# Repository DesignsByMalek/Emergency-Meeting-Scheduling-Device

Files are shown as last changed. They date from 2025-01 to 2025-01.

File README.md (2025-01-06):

# Integrated Documentation: Remote Emergency Meeting Scheduling Device

This comprehensive documentation merges two interconnected projects, combining IoT-enabled emergency scheduling with a Flask application to manage Google services. Together, they offer a robust solution for automating critical communication tasks.

---

## Project Overview

### License

This project is licensed under the Apache License 2.0. You may obtain a copy of the License at:

[Apache License 2.0](http://www.apache.org/licenses/LICENSE-2.0)

Unless required by applicable law or agreed to in writing, software distributed under the License is distributed on an "AS IS" BASIS, WITHOUT WARRANTIES OR CONDITIONS OF ANY KIND, either express or implied. See the License for the specific language governing permissions and limitations under the License.

---

### Remote Emergency Meeting Scheduling Device
An open-source IoT solution designed to automate emergency meeting scheduling. It integrates seamlessly with Google Meet, SMS triggers, and email notifications to enhance reliability and efficiency.

### Flask Application
A lightweight web application utilizing Google services to automate calendar and spreadsheet management, with SMS processing to trigger calendar invites.

---

## Features

### IoT Device Highlights
- **SMS Trigger**: Activates the backend server via Twilio to initiate emergency meeting scheduling.
- **Battery Efficiency**: Operates for over a year on a single battery.
- **Design Optimization**: Iteratively developed for enhanced functionality and aesthetics.
- **Complete Resources**: Includes PCB designs, 3D models, schematics, and manufacturing files.

### Backend Capabilities
- **Google Workspace Integration**: Automates Google Meet scheduling and retrieves client data from Google Sheets.
- **Email Notifications**: Sends meeting details to participants promptly.
- **Scalability**: Handles multiple requests in real-time.

### Flask App Features
- **Google Calendar Management**: Creates and customizes Google Calendar events, including attendees, timings, and reminders.
- **Spreadsheet Management**: Reads, writes, and appends data dynamically to Google Sheets.
- **SMS Processing**: Logs SMS data, retrieves client details, and triggers calendar invites based on the content.

---

## Installation

### Prerequisites
- **Software**: Python 3.8+
- **Google APIs**: Enable Calendar and Sheets APIs in the Google Cloud Console.
- **API Accounts**: Twilio account for SMS handling; OAuth credentials for Google services.

### Setup Steps

#### Clone the Repository
```bash
git clone <repository_url>
cd <repository_folder>
```

#### Install Dependencies
```bash
pip install -r requirements.txt
```

#### Configure API Credentials
- Save the credentials JSON file from Google Cloud in the project directory.
- Add API keys and credentials in `config.py`:
  ```python
  CREDENTIAL_FILE = 'path_to_credentials.json'
  CALENDAR_TOKEN = 'path_to_google_calendar_token.json'
  SHEET_TOKEN = 'path_to_google_sheet_token.json'
  GOOGLE_SHEET = 'spreadsheet_id'
  ```

#### Start the Server
```bash
python app.py
```

---

## Usage

### IoT Device
1. Activate the device to send an SMS trigger to the backend.
2. The backend:
   - Retrieves client details from Google Sheets.
   - Schedules a Google Meet session.
   - Sends email notifications to participants.

### Flask App

#### Calendar Management
- Use the `set_calendar` function to create events:
  ```python
  from modules.calendar_v1 import set_calendar

  invitees = ["example1@gmail.com", "example2@gmail.com"]
  set_calendar(invitees)
  ```

#### Google Sheets Management
- Perform operations with the `GoogleSheets` class:
  ```python
  from modules.sheets_v1 import GoogleSheets

  gs = GoogleSheets()
  # Read data
  data = gs.read_data("Sheet1", "A1:C10")
  print(data)
  # Write data
  values = [["Name", "Age"], ["Alice", 25], ["Bob", 30]]
  gs.write_data("Sheet1", "A1", values)
  # Append data
  new_rows = [["Charlie", 35]]
  gs.append_data("Sheet1", new_rows)
  ```

#### SMS Processing
- Endpoint for SMS:
  ```bash
  /emergency-button/inbound-emergency
  ```
- Example payload:
  ```json
  {
    "From": "+1234567890",
    "To": "+0987654321",
    "Body": "button_id,event_type,battery_health"
  }
  ```
- Functionality:
  - Logs SMS details to the `SMS Logs` sheet.
  - Retrieves client emails from the `Client Info` sheet.
  - Triggers calendar invites based on the SMS content.

---

## GoogleAuthenticator Class for Google API Authentication

### Description
The `GoogleAuthenticator` class is designed to streamline authentication with Google API services. It handles token management, credential verification, and API service building, making it easier to integrate with Google services like Calendar and Sheets.

### How It Works

#### Authentication Process
- Ensures tokens are valid or refreshes them if expired.
- Launches a local server to authenticate and save credentials if no token exists.
- Saves credentials for future use.

#### Service Building
- Builds a Google API service using authenticated credentials for interaction with APIs like Calendar and Sheets.

#### Example Use
- Authenticate and initialize Calendar API service:
  ```python
  from services.authenticator import GoogleAuthenticator

  auth = GoogleAuthenticator(service_name='calendar', version='v3')
  credentials = auth.get_authenticated(token_path='path/to/token.json', scope=['https://www.googleapis.com/auth/calendar'])
  calendar_service = auth.auth_build('calendar', 'v3', credentials)
  print("Calendar API initialized.")
  ```

---

## Python Code Structure

```
project_root/
    |- app/
    |   |- modules/
    |   |   |- calendar_v1.py   # Manages Google Calendar events
    |   |   |- sheets_v1.py     # Manages Google Sheets interactions
    |   |- services/
    |       |- authenticator.py # Google API authentication utility
    |   |- routes/
    |       |- sms.py           # Handles SMS processing and calendar integration
    |   |- config.py                 # Configuration file for environment variables
    |- app.py # Entry point
```
## Python Flow Chart 
Backend Flow chart

---

## Future Improvements

- Enhance error handling for API operations.
- Add support for additional notification methods and triggers.
- Integrate further Google APIs for expanded functionality.
- PCB modifications for better user experience.

## IoT Device Code Highlights

### Key Functionalities
The Arduino code is designed to efficiently manage emergency meeting triggers. Below are the main highlights:

#### 1. **Low Power Mode**
The device leverages the `LowPower` library to maximize battery life by entering sleep mode when inactive.  
Example:
```cpp
#include "LowPower.h"

void sleepNow() {
    LowPower.powerDown(SLEEP_8S, ADC_OFF, BOD_OFF);  // Sleep for 8 seconds
}
```

#### 2. **Button Press Handling**
An interrupt is used to detect button presses and wake the device from sleep mode.
```cpp
const int buttonPin = 2;
volatile bool buttonPressed = false;

void setup() {
    attachInterrupt(digitalPinToInterrupt(buttonPin), wakeUp, FALLING);  // Attach interrupt
}

void wakeUp() {
    buttonPressed = true;  // Set flag on button press
}
```

#### 3. **SIM800L Communication**
The device uses `SoftwareSerial` to communicate with the SIM800L module for sending SMS triggers.
```cpp
#include <SoftwareSerial.h>

SoftwareSerial mySerial(3, 4);  // SIM800L Tx & Rx connected to pins 3 & 4

void sendSMS() {
    mySerial.begin(9600);
    mySerial.print("AT+CMGF=1
");  // Set SMS mode
    mySerial.print("AT+CMGS="+1234567890"
");  // Specify recipient
    mySerial.print("Emergency meeting triggered.
");  // Message content
    mySerial.write(26);  // End message with CTRL+Z
}
```
---

## Arduino Flow Chart
Arduino Flow chart

---

### Full Code
The complete code is available in the GitHub repository.

---

## Assembly Animation
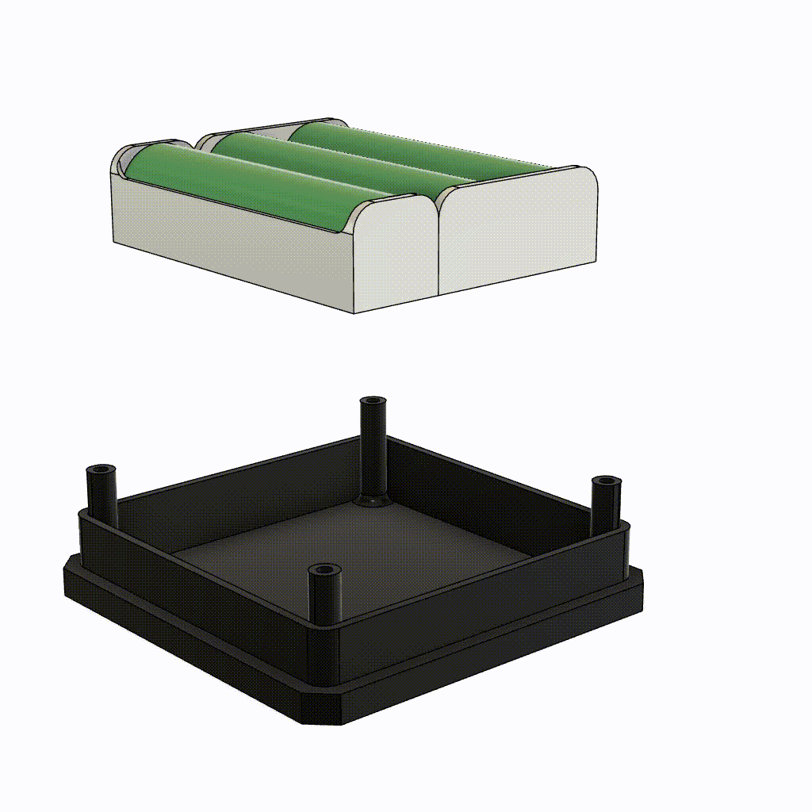
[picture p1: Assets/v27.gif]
Assembly Video


---

## Done By

This project was created and maintained by:

- [GitDevKarim](https://github.com/GitDevKarim)
- [DesignsByMalek](https://github.com/DesignsByMalek)

Feel free to reach out to us for any questions or contributions!

<div style="display: flex; justify-content: center; align-items: center;">
  <div style="text-align: center; margin-right: 20px;">
    <h3>GitDevKarim</h3>
    <span style="display: inline-block; margin-right: 10px;">
      <a href="https://github.com/GitDevKarim">
        
      </a>
    </span>
    <span style="display: inline-block;">
      <a href="https://linkedin.com/in/karim-jibai001">
        
      </a>
    </span>
  </div>

  <div style="text-align: center; margin-left: 20px;">
    <h3>DesignsByMalek</h3>
    <span style="display: inline-block; margin-right: 10px;">
      <a href="https://github.com/DesignsByMalek">
        
      </a>
    </span>
    <span style="display: inline-block;">
      <a href="http://www.linkedin.com/in/malek-itani-3a346b269">
        
      </a>
    </span>
  </div>
</div>

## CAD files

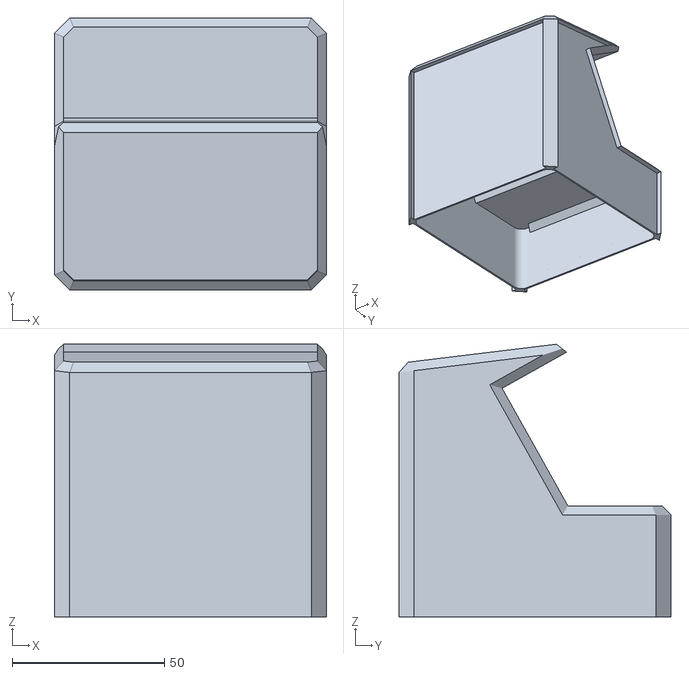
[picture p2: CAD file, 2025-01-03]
3D Models/For 3D Printing/main box w acryllic covers.stl
89.2 x 89.2 x 89.4

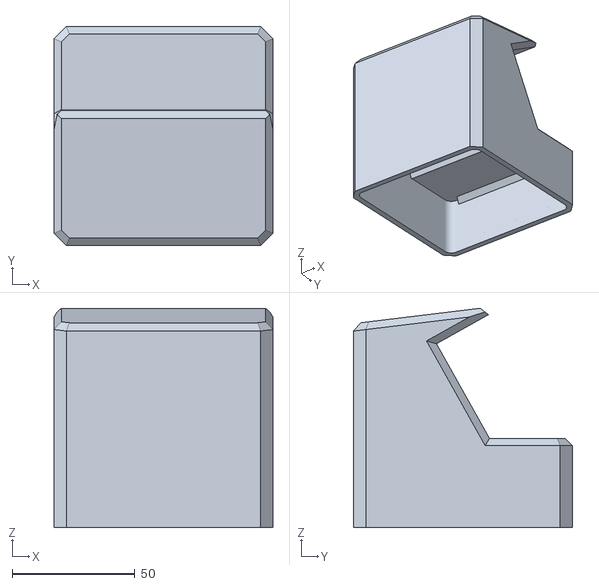
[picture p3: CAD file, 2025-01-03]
3D Models/For 3D Printing/main box full 3d print.stl
89.2 x 89.2 x 89.4

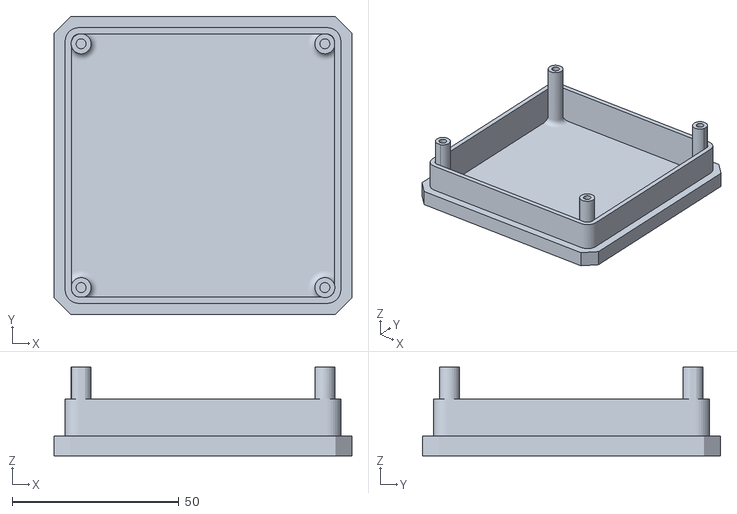
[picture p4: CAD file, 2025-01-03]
3D Models/For 3D Printing/Base.stl
89.2 x 89.2 x 26.6

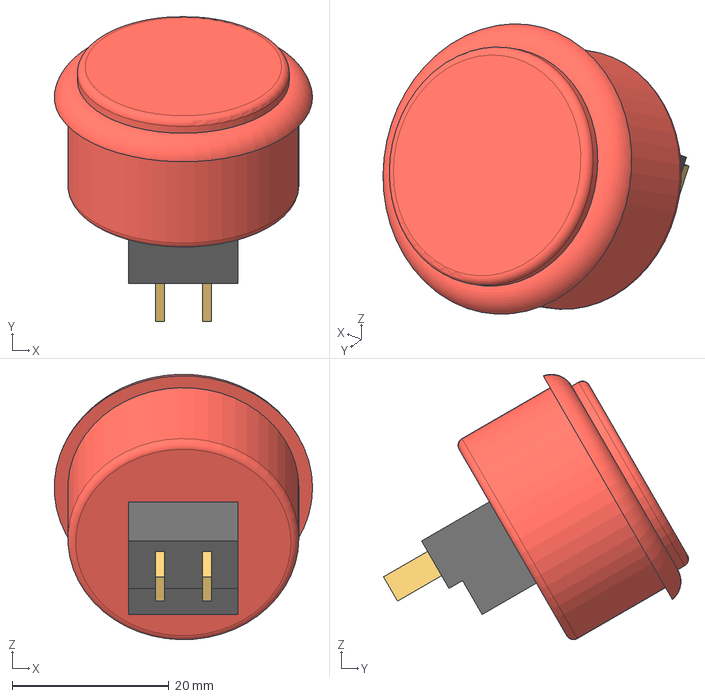
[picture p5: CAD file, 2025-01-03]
3D Models/sanwa button v5.step
33.0 x 38.9 x 33.9 mm

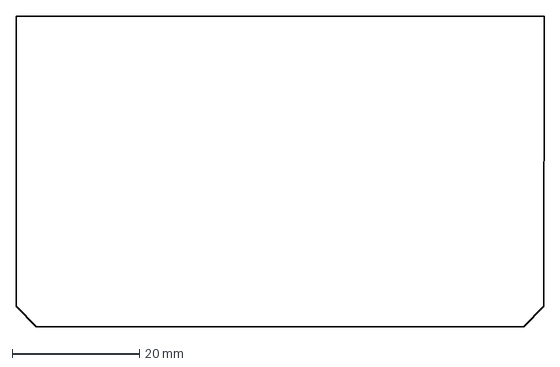
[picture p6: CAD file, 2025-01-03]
Laser Cutting Files/cover 3.dxf
83.0 x 48.8 mm

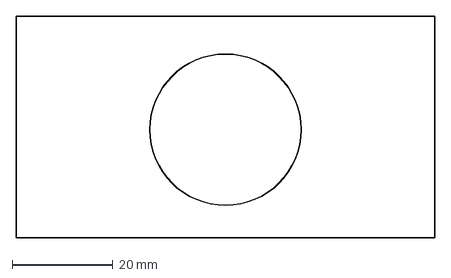
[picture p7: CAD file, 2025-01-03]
Laser Cutting Files/cover 1.dxf
82.9 x 43.9 mm

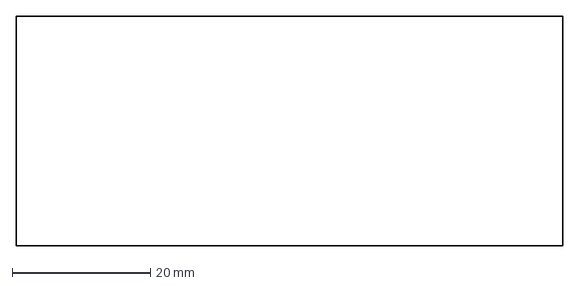
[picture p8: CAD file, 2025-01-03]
Laser Cutting Files/cover 7.dxf
79.0 x 33.2 mm

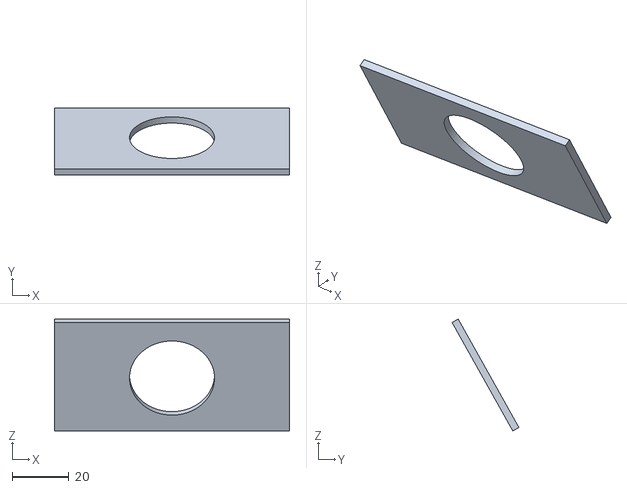
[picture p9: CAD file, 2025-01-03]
3D Models/For 3D Printing/button cover (if 3d printed).stl
82.9 x 23.6 x 39.5

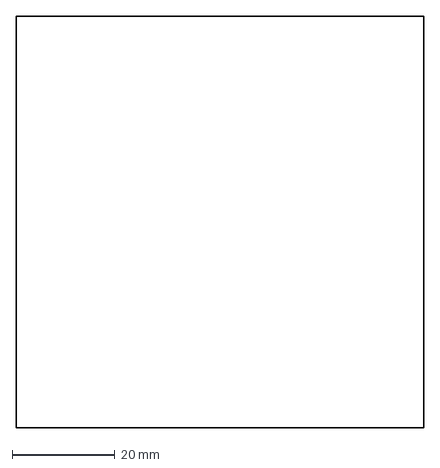
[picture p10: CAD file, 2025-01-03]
Laser Cutting Files/cover 5.dxf
79.0 x 80.0 mm

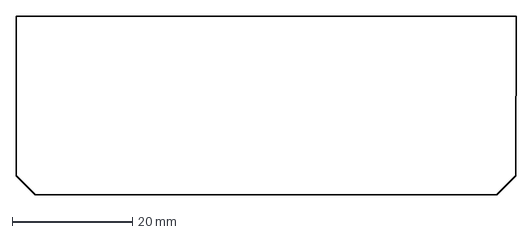
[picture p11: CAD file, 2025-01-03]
Laser Cutting Files/cover 2.dxf
83.0 x 29.6 mm

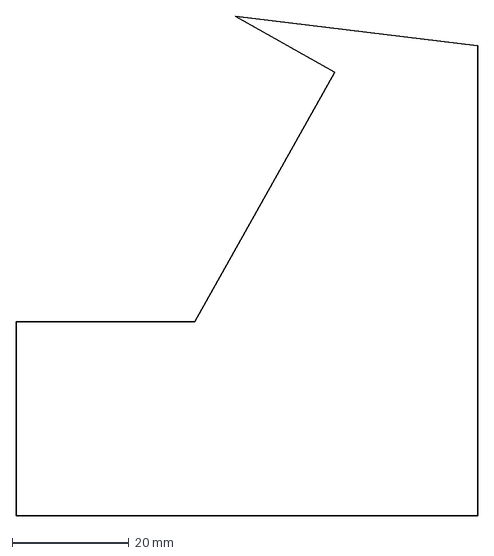
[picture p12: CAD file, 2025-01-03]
Laser Cutting Files/cover 6.dxf
79.0 x 85.6 mm

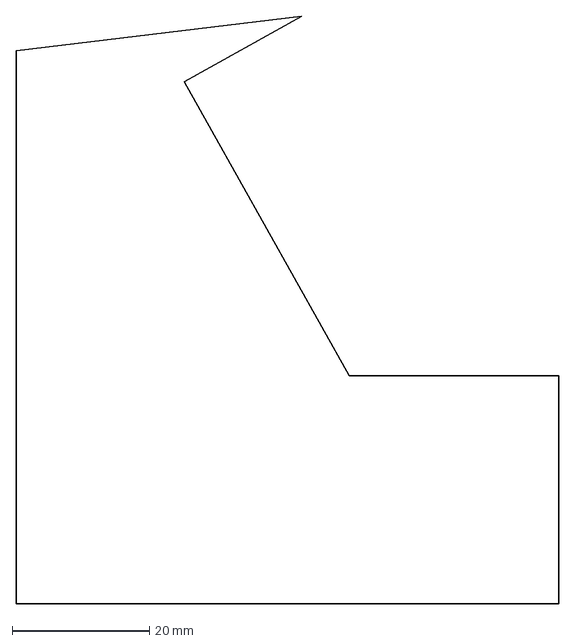
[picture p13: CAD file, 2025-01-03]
Laser Cutting Files/cover 4.dxf
79.0 x 85.6 mm

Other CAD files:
3D Models/sanwa button v5.f3d

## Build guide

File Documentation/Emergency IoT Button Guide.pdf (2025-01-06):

DesignsByMalek | GitDevKarim

i

## PRODUCT DESIGN AND MANUFACTURING

## OPEN-SOURCE DOCUMENTATION

## REMOTE EMERGENCY MEETING SCHEDULING DEVICE

## VERSION 1

Designed by

## ENG. MALEK M. ITANI

## ENG. KARIM A. JIBAI

Submitted to

## THE PUBLIC DOMAIN

## JANUARY 2025

ii

ABSTRACT

This report provides an in-depth exploration of the design, development, and

deployment of the Remote Emergency Meeting Scheduling Device, a versatile, open-source

IoT solution designed to streamline emergency communication. This device, a single-button

unit housed in an ergonomic enclosure, is built to trigger urgent Google Meet scheduling via

GSM-based SMS communication, circumventing potential vulnerabilities of Wi-Fi networks.

Its robust integration of hardware, software, and backend technologies ensures reliability,

security, and scalability, making it suitable for various industries such as corporate

environments, healthcare, education, and emergency services.

The report details the iterative design process, from 3D modeling the enclosure to

electronic circuit design and PCB layout, and backend server integration that manages

scheduling and notifications. It also includes comprehensive instructions for manufacturing,

assembly, and setup, allowing for replication and customization. By adhering to an open-

source model, this solution encourages adaptability, enabling users to customize the system

for diverse applications. Addressing challenges such as regulatory compliance, hardware

optimization, and software efficiency, the report positions the device as a practical, scalable,

and cost-effective emergency communication tool adaptable to many industries.

iii

## TABLE OF CONTENTS

1.1- | Background information
1.2- | Aim of the Project
2.1- | Electronic Circuit Design
2.2- | Arduino Programming
2.3- | Backend Code and Server Setup Instructions
2.4- | 3D Modeling
2.5- | Manufacturing and Assembly Instructions
3.1- | Results
3.2- | Trouble Shooting
3.3- | Future Improvements
3.4- | Regulations and Legality

## 1. INTRODUCTION

### 1.1 Background Information

In fast-paced and high-stakes environments, the ability to rapidly respond to

emergencies is essential. Whether in corporate settings, healthcare facilities, educational

institutions, or industrial environments, effective communication during crises can mitigate

risks, minimize downtime, and save lives. Recognizing this critical need, the Remote

Emergency Meeting Scheduling Device was developed as an innovative, open-source IoT

solution designed to simplify and accelerate emergency response coordination.

The device operates with a single press of a button, sending a GSM-based SMS to a

backend server that schedules a Google Meet session and sends instant notifications to

relevant stakeholders. Unlike traditional methods that depend on manual scheduling or Wi-Fi

connectivity, this solution offers unmatched reliability by leveraging GSM communication,

making it suitable even in areas with limited internet access. Additionally, the system's

scalability and adaptability allow it to be applied across various sectors. For example, in the

corporate world, it ensures urgent client communication; in healthcare, it can summon

emergency teams; in educational institutions, it facilitates swift administrative coordination

during crises.

The project’s design emphasizes security, user-friendliness, and aesthetics. Its long-

lasting battery supports over a year of uninterrupted operation, while its modular backend

system integrates seamlessly with popular tools like Google Sheets, Twilio, and Google

Calendar. Designed to be replicated, modified, and scaled, this open-source solution provides

a reliable and affordable emergency communication tool adaptable to various industries,

empowering organizations to manage crises effectively and efficiently.

### 1.2 Project Aim

The aim of this project is to create an open-source, scalable IoT device that offers a

reliable, user-friendly, and secure solution for emergency meeting scheduling. The device is

designed to be adaptable across various fields, such as corporate environments, healthcare,

educational institutions, and emergency response scenarios. Its primary objectives include

simplifying emergency communication by enabling users to schedule urgent Google Meet

meetings with a single button press, ensuring that notifications and meeting links are quickly

delivered to all stakeholders. The system is built with scalability and flexibility in mind,

allowing it to meet the diverse needs of industries ranging from medical teams to corporate

crisis management. The device is optimized for long-lasting operation, with over a year of

battery life achieved through hardware and software enhancements, ensuring reliable

performance with minimal maintenance. To enhance security, the device utilizes GSM

technology, bypassing Wi-Fi network vulnerabilities to provide a stable and secure

communication channel. Additionally, the project will be open-source, with detailed

documentation, code, and design files available for users to replicate, customize, and scale

the device to suit their specific requirements. The device will also feature an aesthetic and

functional design, balancing professional appearance with intuitive usability. By combining

robust hardware, efficient software, and a user-centric approach, this device aims to

transform emergency communication, providing a cost-effective and versatile solution for a

wide range of applications. The open-source nature invites collaboration and innovation,

empowering the community to expand the device’s potential beyond its original design.

Figure 1 shows the block diagram of the project functionality.

FIGURE 1: FLOW DIAGRAM OF HOW THE DEVICE SHOULD WORK

## 2. METHODS

### 2.1 Electronic Circuit Design

### 2.1.1 Components

This section outlines the steps taken to design the circuitry for the IoT emergency

button device, detailing the components used, their roles, and the process to create a reliable

and functional electronic system. The button serves as an auxiliary device, primarily

responsible for sending SMS messages via GSM to initiate the meeting scheduling process.

Key requirements include a battery life exceeding 365 days, reliable signal connectivity even

in challenging conditions such as underground environments, and the use of rechargeable

lithium-ion batteries for long-term, low-maintenance operation. The design ensures robust

GSM network connectivity under tough conditions, making the device dependable in critical

scenarios. Table 1 Shows the electronic components used in this project:

### 1. Arduino Nano

The Arduino Nano is a compact, microcontroller-based

development board based on the ATmega328P

microcontroller. It is designed to be breadboard-friendly,

making it ideal for prototyping, embedded systems, and

small electronics projects. The board operates on a 5V

supply, powered through a mini-USB connection or an

external power source. It features 14 digital input/output

pins, 8 analog inputs, a 16 MHz clock speed, and a built-in

USB-to-serial converter, making it suitable for and IoT

(Internet of Things) system.

FIGURE 2: ARDUINO NANO

### 2. SIM800L V2 EVB with Antenna

The SIM800L V2 is an upgraded, more reliable GSM/GPRS

module for SMS, voice calls, and data transfer over 2G

networks. It consumes 2-10mA in idle mode and 100-200mA

when sending SMS. During data transfer or calls, it can draw

up to 2A, requiring a stable 5V power supply. The V2

version includes a more powerful antenna for better signal

FIGURE 3: SIM800L V2 EVB reception, making it ideal for IoT, remote monitoring, and

cellular communication projects.

### 3. MT3608 DC-DC Step Up Converter

The MT3608 is a compact and efficient DC-DC step-up

(boost) converter that increases input voltages from 2V to

24V up to an adjustable output of 5V to 28V. It can deliver

up to 2A of output current, depending on input and output

conditions. Known for its high efficiency, typically around

85-90%, the MT3608 is commonly used in battery-powered

devices, portable power supplies, and LED drivers. Its small

size and reliability make it ideal for various electronics

projects requiring voltage step-up functionality.

FIGURE 4: MT3608

### 4. HK4100F 3V Relay

The HK4100 is a compact 3V relay commonly used in low-

power electronic projects for switching high-current loads

with a low-voltage control signal. It features a 3V coil

voltage and can handle up to 10A of current at 120V AC or

30V DC. This relay is widely used in automation systems,

control circuits, and devices requiring safe switching of high-

power components. Its small size and reliable performance

make it a popular choice for microcontroller-based

applications where low voltage control and high current

switching are needed.

FIGURE 5: HK4100F 3V

RELAY

### 5. SMA Female IPX Coaxial Cable (Right Angled)

The SMA Female to IPX Coaxial Cable is designed for

connecting devices with SMA female connectors to those

with IPX connectors, providing reliable RF signal

transmission. It is commonly used in wireless

communication systems, antennas, and RF modules. This

cable is available in a version with a PCB-mounted SMA

female connector featuring four legs for secure mounting. It

offers flexible, low-loss signal transmission, making it ideal

for compact electronics projects, IoT applications, and

devices requiring high-frequency signal connectivity.

FIGURE 6: ANTENNA SMA

TO IPX CONNECTOR

6. 1N4007 Diode

The 1N4007 is a general-purpose rectifier diode commonly

used for rectifying AC to DC in power supply applications. It

has a peak reverse voltage of 1000V and can handle a

forward current of up to 1A. In addition to its use in power

supplies, the 1N4007 is often used as a freewheeling diode

(flyback diode) across relay coils to protect circuits from

voltage spikes generated when the relay is turned off. Its

durability, high voltage rating, and reliability make it ideal

for protecting sensitive components in automotive, industrial,

and electronic systems.

FIGURE 7: 1N4007 DIODE

### 7. JST XH 2.54 Male and Female Connectors

The 2-pin JST female and male connectors are commonly

used in electronics for providing a secure and compact

connection between two components. These connectors are

widely used in power supplies, batteries, and signal

transmission applications. The male connector typically has

two pins that are inserted into the female connector, ensuring

a reliable connection. They are designed for easy and secure

installation, making them ideal for use in various projects,

including robotics, IoT devices, and other compact electronic

systems that require efficient, low-profile connections. For

this application 3 of 3 each are required.

FIGURE 8: JST

CONNECTORS

8. 104 Ceramic Capacitor

The 104 ceramic capacitor is a widely used passive

component with a capacitance of 100nF (nano-farads), often

utilized for decoupling, filtering, and smoothing in electronic

circuits. It helps prevent accidental button presses caused by

electrical noise by stabilizing the voltage and reducing signal

interference. The capacitor is known for its small size,

reliability, and stability across a range of voltages, making it

ideal for power supply circuits, signal filtering, and noise

reduction. It is commonly used in consumer electronics,

automotive, and industrial devices.

FIGURE 9: 100NF CERAMIC

CAPACITOR

### 9. Sanwa 30mm Red Button

The 30mm Sanwa red button is a durable and widely used

push-button switch commonly found in arcade machines,

gaming controllers, and electronic projects. Known for its

high-quality construction, it provides reliable operation and a

tactile feel when pressed. This button is often used for user

input in various applications, and its large size makes it easy

to press. It is designed to minimize accidental activation,

ensuring precise control, and is ideal for projects requiring

robust, responsive switches, such as in gaming, robotics, and

DIY electronics. This model comes with a screw mechanism

to fix it securely in place.

FIGURE 10: SANWA RED

BUTTON

10. 18650 Battery

The 18650 battery is a widely used rechargeable lithium-ion

cell known for its high energy density and long cycle life.

With a nominal voltage of 3.7V and typical capacities

ranging from 1800mAh to 3500mAh, it is commonly used in

portable electronics, power tools, and electric vehicles. The

18650 battery is known for its reliability, compact size, and

efficiency, making it ideal for applications requiring a stable

power source, such as in battery packs for laptops,

flashlights, and IoT projects. Three will be used for this

project.

FIGURE 11: 18650 LITHIUM

ION BATTERY

### 11. Single Cell 18650 Battery Holder

The single-cell 18650 battery holder is designed to securely

hold a single 18650 lithium-ion battery, providing a reliable

power source for various electronic projects. With its

compact and durable design, it is ideal for powering low-

voltage devices, such as an Arduino board. This holder

ensures easy installation and removal of the battery, while

maintaining a stable connection to power the Arduino and

other small electronics. It is commonly used in DIY projects,

robotics, and portable power supplies, offering an efficient

solution for battery-powered

FIGURE 12: 18650 SINGLE

CELL HOLDER

### 12. Two Cell Parallel 18650 Battery Holder

The 2-cell parallel 18650 battery holder is designed to hold

two 18650 lithium-ion batteries in parallel, providing

increased capacity and current output. This holder ensures a

stable and reliable power source for high-current devices,

such as the SIM800L module, which requires more current

than a single cell can provide. By connecting the batteries in

parallel, the holder doubles the available capacity while

maintaining a consistent voltage of 3.7V, making it ideal for

powering power-hungry components like the SIM800L,

which is used in IoT and communication projects.

FIGURE 13: 18650 TWO

CELL PARLLEL HOLDER

### 13. Male Pin Headers

Male pin headers are widely used for PCB mounting,

providing a secure connection for electronic components.

These headers consist of rows of metal pins, usually spaced

2.54mm apart, which are soldered onto the PCB. They are

commonly used to connect components, such as sensors or

modules, to the PCB, allowing for easy and removable

connections. They are a standard choice for creating

customizable and accessible connections in electronic

designs.

FIGURE 14: MALE PIN
HEADERS

### 2.1.2 Circuit Functionality and Explanation

Many Iterations of the circuit were made but for this section we will only discuss the

working circuit. The circuit design revolves around the Arduino as the central control unit,

with careful attention to power management, signal integrity, and efficient use of

components. The Arduino is powered by a single 18650 lithium-ion battery, this dedicated

power source provides consistent performance and isolates the Arduino's operation from

other high-current sections of the circuit.

The button is wired to one of the Arduino's GPIO pins, specifically interrupt pin 2, as

the Nano has limited interrupt pins (2 and 3). A debounce capacitor is placed across the

button's terminals to smooth out mechanical noise and eliminate erratic signals caused by

button bounces and random noise, ensuring a clean and reliable signal is sent to the Arduino.

The button serves as the primary input mechanism, triggering the circuit's operations. When pressed, it connects the pin to ground, providing a suitable trigger for the Arduino to wake

up.

A 3V relay is incorporated to manage the power supply to the SIM module. The relay

coil is driven directly by the Arduino's GPIO output through a low-current connection. A

flyback diode is placed across the relay coil to handle voltage spikes generated when the coil

is de-energized. This protects the circuit from damage and ensures the longevity of the relay.

The relay serves as an electrical switch, allowing the SIM module to remain completely

disconnected from its power source until required, thereby conserving energy.

The SIM800L V2 was used for this project as the SIM800L V1, after rigorous testing,

was found to be less reliable than the V2 and required 2 additional resistors to operate. The

SIM800L V1 should work fine for this circuit but we decided to go with the V2 as it required

less trouble shooting and simple at the expense of it being operated at 5V instead of 3.7-4.2.

Also, the antenna that came with the SIM800L V1 had very poor connectivity and required a

separate antenna to be bought with it whereas the V2 came with a robust antenna. The SIM

module is powered by two parallel 18650 lithium-ion batteries, chosen for their ability to

provide the substantial current required during GSM transmission. These batteries are

connected through appropriate wiring to ensure a stable power supply, with an MT6803 boost

converter employed to step up the lithium-ion batteries' voltage range of 3.5–4.2V to a stable

5V. This boosted voltage is necessary to meet the operating requirements of the SIM module

and maintain its performance under varying power conditions. Additionally, bypass

capacitors are strategically placed close to the SIM module's power input. These capacitors

play a crucial role in mitigating voltage fluctuations that may arise from sudden current

surges during transmission, effectively smoothing out the power supply and ensuring the SIM

module functions reliably even under demanding conditions. More information on the

sim800L can be found in reference [1].

Following the manufacturer's recommendations, it is best practice to turn on the SIM

module by first connecting it to ground and then supplying Vcc. In low-voltage systems, such

as those operating at 3.7V, both high-side and low-side switching can be challenging. Low-

side switching, in particular, may suffer from voltage drops across the MOSFET, leading to

inefficiencies and insufficient voltage for reliable operation. In these cases, a relay offers a

simpler and more effective solution for controlling the SIM module’s power supply,

bypassing the complexities of MOSFET switching and ensuring stable power delivery. Make sure to wire a freewheeling diode across the terminals of the relay coil to prevent a reverse

current in the direction of the Arduino when the relay turns off and thus damaging it.

An external antenna is attached to the SIM module via a dedicated connector to

enhance signal reception. This antenna is positioned to maximize GSM network connectivity,

ensuring stable communication even in challenging environments such as underground

locations. The overall layout of the circuit prioritizes efficiency and reliability, making the

design robust and suitable for long-term use. Figure 13 shows the block diagram of the

circuit.

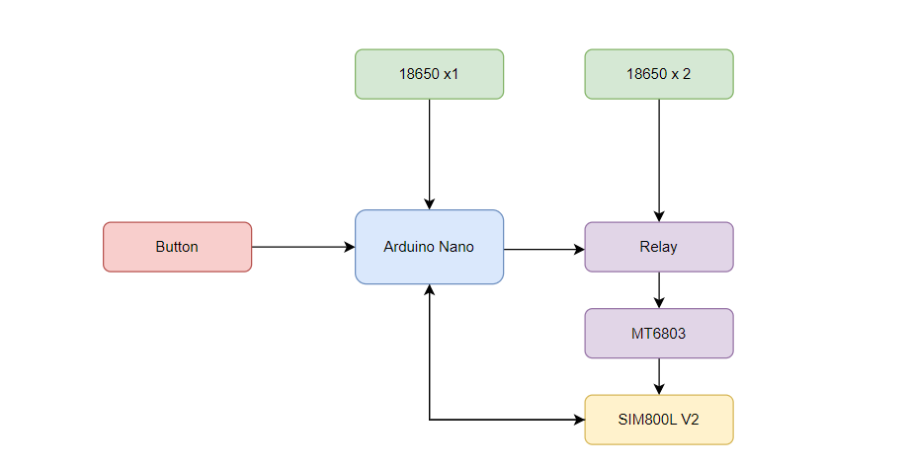
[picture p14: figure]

FIGURE 15: BLOCK DIAGRAM OF CIRCUIT

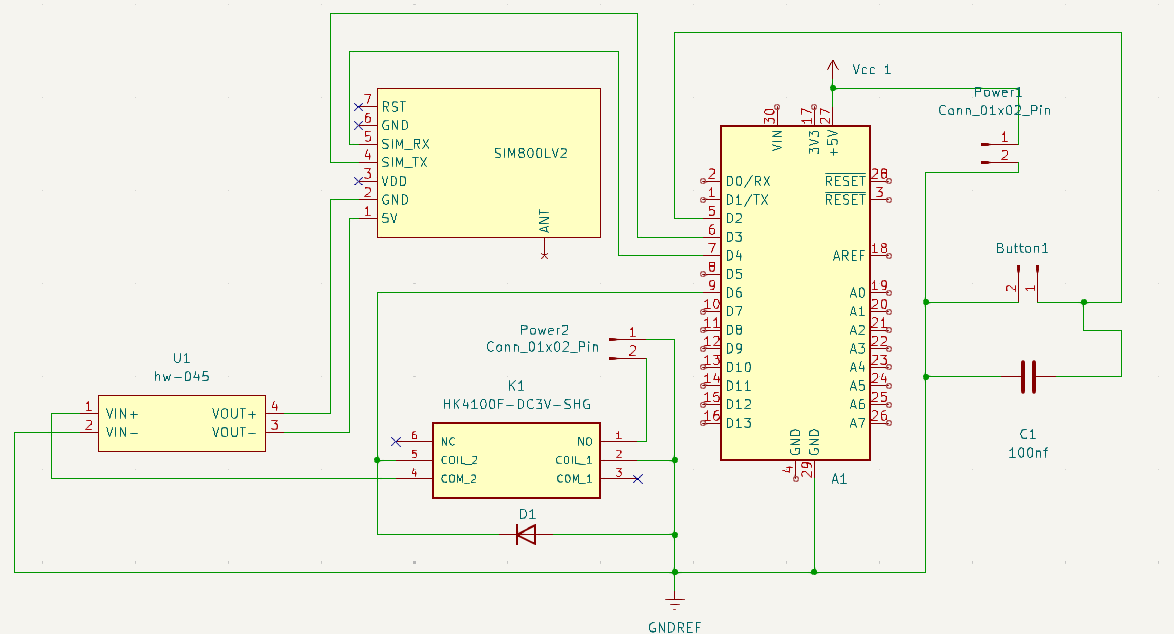
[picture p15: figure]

FIGURE 16: KICAD SCHEMATIC OF CIRCUIT.

The circuit was designed using KiCad, the schematic is shown in figure 15. This

schematic can be replicated on a prototyping board for a better understanding of how the

system works. When using Ki-Cad, make sure to install the necessary libraries and Files to

modify the circuit. Some files are custom made. Feel free to explore KiCad libraries.

There are several important considerations regarding the circuit that should be kept in

mind to ensure optimal performance and avoid potential mistakes. These notes will help

increase the efficiency of the system and ensure smooth operation throughout the project.

The relay is used in this project to control the power supply to the SIM module. Below

is the pinout diagram of the relay:

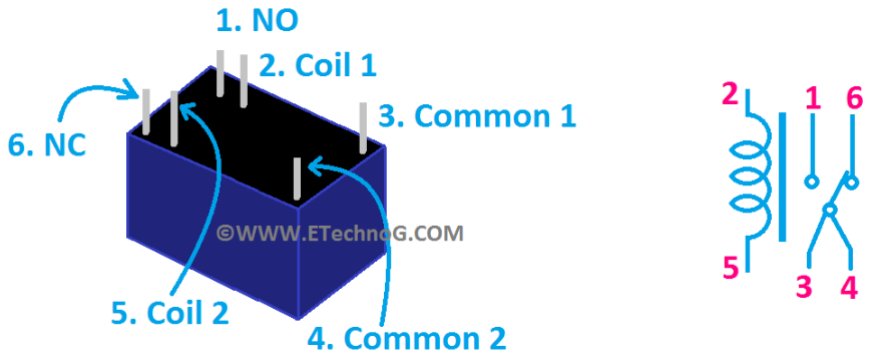
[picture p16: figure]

FIGURE 17: RELAY PINOUT

The relay uses the following pins for operation: Pin 2 (Control, IN) is connected to the

control signal from the Arduino. Pin (Normally Open, NO) connects to the load (SIM

module), while Pin 4 (Common, COM) is the shared pin used to switch the load on or off. Pin

6 (Normally Closed, NC) provides an alternative connection when the relay is in the off state

(Not Connected). A freewheel diode, also known as a flyback diode, is crucial for protecting

the circuit from voltage spikes caused by inductive loads, such as relays or motors. When the

relay coil is de-energized, the collapsing magnetic field can generate a high voltage in the

opposite direction, potentially damaging components. The freewheel diode provides a safe

path for the current to dissipate, preventing damage to the circuit and ensuring reliable

operation.

The Arduino Nano’s TX (Transmit) and RX (Receive) pins are connected to the

SIM800L module for serial communication. Specifically, Pin 3 on the Arduino Nano (RX) is

used for TX of the SIM module, and Pin 4 is used for RX of the SIM. This setup allows the

Arduino to send and receive data from the SIM800L, such as commands for sending SMS or

making calls. If there is no communication between the SIM module and the Arduino, make

sure these pins are connected properly.

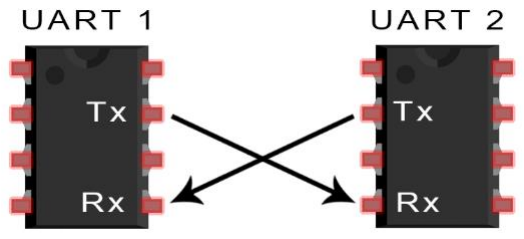
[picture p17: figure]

FIGURE 18: SERIAL COMMUNICATION BETWEEN ARDUINO AND SIM MODULE

For the power and button connections, 2-pin JST 2.54mm female connectors are used.

These connectors provide a secure and easy-to-use interface for plugging in the power supply

and the button that controls the SIM module.

There are three male JST connectors: Power 1, Power 2, and Button. These connectors

are color-coded for easy identification, with the red wire indicating positive voltage (Vcc)

and the black wire indicating ground (GND). It is important to ensure that all three male JST

connectors are consistent, with the red and black wires on the same side of each connector.

Warning: Make sure the red and black wires are on the same side of all three

connectors to avoid reversing the connections. Incorrect connections may cause damage to

the circuit or components.

Power 1 is connected to a single lithium-ion battery, as it is solely responsible for

powering the Arduino, which has a relatively low current requirement. Power 2, on the other

hand, is dedicated to powering the SIM module. To meet the SIM module's high current

demand, especially during its boot-up phase, two lithium-ion batteries are connected in

parallel. This setup prevents voltage drops in the Arduino's power supply, which could

otherwise cause it to reset when the SIM module draws its high inrush current during startup.

Common ground is established between the 2 power supplies so that the circuit functions

properly. The sim module cannot communicate with the Arduino if there is no common

ground.

### 2.1.3 PCB Design

To integrate all components into a single compact unit, a PCB (Printed Circuit Board)

was designed using KiCad. This design ensures a neat arrangement of components with

minimal wiring, reducing noise and improving reliability. To keep things compact, the pcb

size is set to be 8 x 8 cm with screw holes on the corners to accommodate 3mm screws. The

traces are designed to avoid passing under the antenna to eliminate noise, and to keep the

MT3608 as far as possible from the GSM module as possible to reduce signal interference

and noise. For simplicity and cost efficiency, the circuit was implemented as a single-layer

PCB, which is easier to manufacture and more affordable. The prototype PCB was

manufactured in-house but can also be easily outsourced to companies like JLCPCB or

PCBWay, with much higher quality and fast delivery, often within a week, for just a few

dollars. Figure 19 shows the PCB Layout.

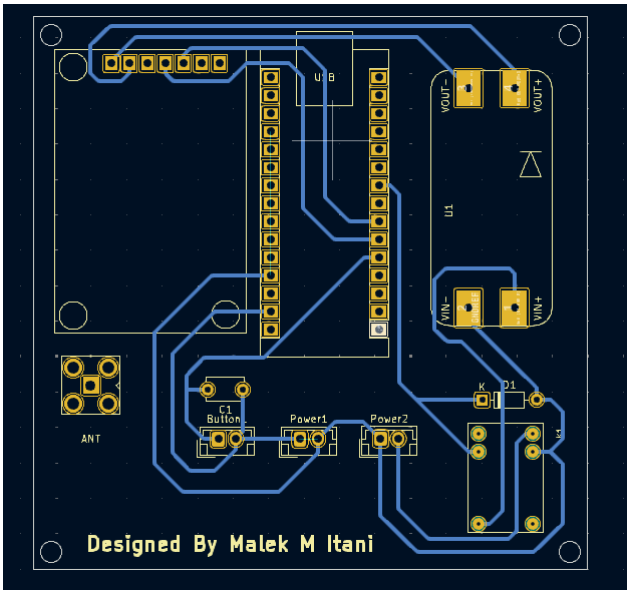
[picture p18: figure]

FIGURE 19: PCB LAYOUT OF THE CIRCUIT

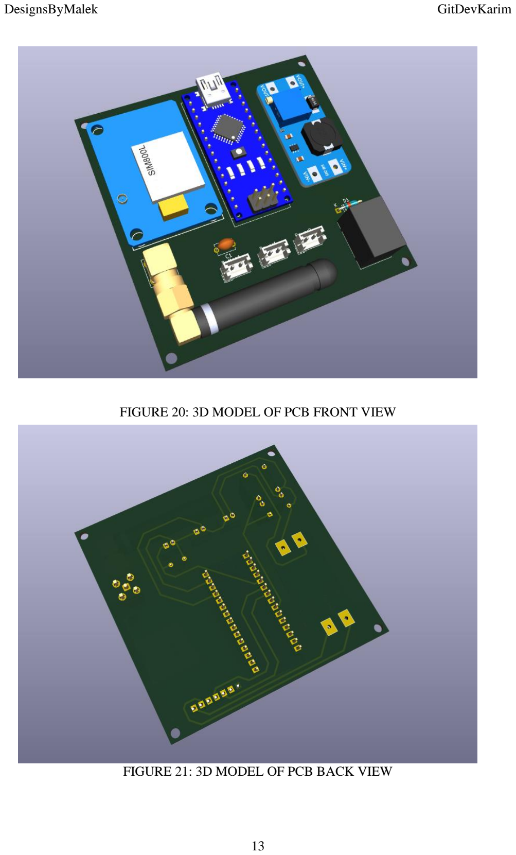
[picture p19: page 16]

FIGURE 20: 3D MODEL OF PCB FRONT VIEW

FIGURE 21: 3D MODEL OF PCB BACK VIEW

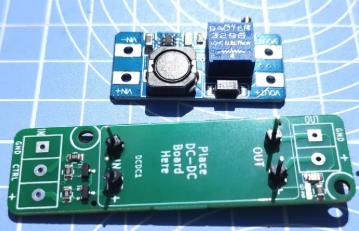
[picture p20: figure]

FIGURE 22: SAMPLE MOUNTING OF MT3608 ON PCB

For the MT3608, male pin headers should be soldered on the pad holes first then the

module should be soldered and mounted as shown in the example board in figure 23:

The antenna mounts on the PCB and is soldered firmly in place using the SMA through

hole component which is spaced and designed to keep it compact and inside the PCB

boarders. This concludes the electronic design part of the project.

### 2.2 Arduino Programming

The Arduino code serves as the foundation for a low-power IoT device that sends an

SMS notification when a button is pressed. It is designed to operate efficiently by utilizing

interrupt-driven inputs and low-power sleep modes. When a button press is detected, the

system wakes up from sleep, powers on the SIM800L GSM module, connects to the cellular

network, sends a pre-programmed SMS, and then powers down again to conserve energy.

This setup is ideal for applications such as emergency alerts or remote monitoring systems.

The code integrates the SoftwareSerial library for communication with the SIM800L module

and the LowPower library to implement energy-saving features. The entire code is included

in Appendix A for reference. The block diagram of the code is shown in figure 24.

FIGURE 23: ARDUINO CODE FLOW DIAGRAM

The code begins with the inclusion of two libraries. The SoftwareSerial.h library allows

serial communication with the SIM800L module using non-default pins, freeing up the

Arduino’s hardware UART for debugging. The LowPower.h library provides functionality to

place the Arduino into deep sleep, minimizing power consumption when the device is idle.

Pin definitions are established next, with buttonPin (pin 2) assigned to the button input,

relayPin (pin 6) controlling the MOSFET that powers the SIM800L, and ledPin (pin 13) for

status indication via an LED. A boolean variable, buttonPressed, is used as a flag to indicate

when the button is pressed. Note that for V1 of this product, the Arduino’s onboard LED is

used.

The SoftwareSerial object, mySerial, is instantiated to communicate with the SIM800L

module via pins 3 (Rx) and 4 (Tx). This enables the Arduino to send and receive AT

commands to the GSM module.

The wakeUp() function is defined as an interrupt service routine (ISR) that sets the

buttonPressed flag to true whenever the button is pressed. This ISR is triggered by a falling

edge on buttonPin. A falling edge is used as a trigger because the button is wired with a

pullup resistor meaning that initially, its set high, and it becomes low when the button is

pressed and the interrupt pin is conneted to ground

In the setup() function, all pins are configured, and initial states are established. The

buttonPin is set as an input with an internal pull-up resistor to ensure stability, while relayPin

and ledPin are set as outputs, starting in the LOW state to ensure the SIM800L module is

initially powered off. Serial communication with the SIM800L is initialized at 9600 baud.

The main program logic resides in the loop() function. It begins by attaching an

interrupt to the buttonPin to detect a button press, then places the Arduino into a deep sleep

mode using LowPower.powerDown(). The device remains in this state until the ISR (Interupt

service routine) is triggered by the button press. Upon waking, the interrupt is detached, and

the LED briefly flashes to indicate activity.

When using an interrupt to wake up the Arduino from sleep mode, pressing the button

again after the Arduino has already woken up won't trigger another interrupt because the

interrupt flag has already been cleared when the Arduino is woken up. In most

microcontrollers, including the Arduino, interrupts are edge-triggered, meaning they only

respond to changes in the signal (e.g., a button press or release). When the Arduino wakes up,

the interrupt flag is cleared, and the microcontroller no longer detects a new edge unless the

button is pressed and released again, causing another transition in the signal. Simply pressing

the button again while the Arduino is awake won't generate a new interrupt signal, as there is

no edge (change in state) being detected at that moment.

The code then powers on the SIM800L module by setting relayPin to HIGH and waits

for two seconds to allow the module to stabilize. The waitForNetwork() function is called to

check the network connection status by sending the AT+CREG? command to the SIM800L

repeatedly for up to 60 seconds. If the network connection is successful, the sendSMS()

function is invoked to send an SMS. The SMS is sent using a series of AT commands: the

mode is set to SMS text format (AT+CMGF=1), the recipient's phone number is specified,

and the message content is sent, followed by a special character (Ctrl+Z) to complete the

transmission.

After the SMS is sent, the SIM800L module is powered off by setting relayPin to

LOW. The LED flashes again to indicate that the system is returning to sleep mode. The loop

then restarts, reattaching the interrupt and placing the Arduino into deep sleep until the next

button press.

The code includes additional utility functions such as updateSerial() to facilitate

debugging by forwarding GSM module responses to the serial monitor. Overall, the program

is designed to be efficient and modular, ensuring low power consumption while reliably

handling GSM communication. The full Arduino code is provided in Appendix A for

implementation and further study.

For debugging purposes, you can uncomment the Serial.print statements by removing

the 2 slashes in the code to view real-time data and monitor the Arduino’s behavior via the

Serial Monitor. Currently, these Serial.print statements are commented out to reduce

unnecessary serial communication during normal operation. By uncommenting them, you can

track variable values, execution flow, and other important outputs, which can be very helpful

in identifying issues or verifying that the circuit and code are functioning as expected.

### 2.3 Backend Code

The backend system for the IoT emergency button is a robust and modular platform

designed to manage emergency communication seamlessly. It serves as the bridge between

the IoT device, Google services, and end-users by processing button triggers, scheduling

Google Meet sessions, and sending email notifications. The system is implemented using

Flask, a lightweight Python web framework, and integrates essential APIs, including Twilio

for SMS handling, Google Calendar for meeting scheduling, and Google Sheets for client

data management. This modular approach ensures scalability, maintainability, and fault

tolerance, making it ideal for handling real-time events efficiently. Figure X shows the flow

diagram of the backend.

The database in this system is designed to manage client information and their

interactions effectively. It includes two main tables: Client Data and SMS Logs. The Client

Data table stores essential details about each client, such as their name, email(s), phone

number, and a unique button ID, The client data is submitted via a Google Form. Multiple

emails for a single client can be added, separated by commas, allowing the system to handle

clients with more than one contact. The SMS Logs table records the events triggered by button presses, such as event types (button press or battery health), along with the

corresponding button ID and battery health information. These Tables can be found and

monitored on Google sheets. The two tables are connected through the button ID, linking the

client details from the Client Data table with the events in the SMS Logs table. This structure

allows the system to identify relevant clients and their associated emails when scheduling

meetings, ensuring that all the specified email addresses for a client are notified of the events

recorded in the logs.

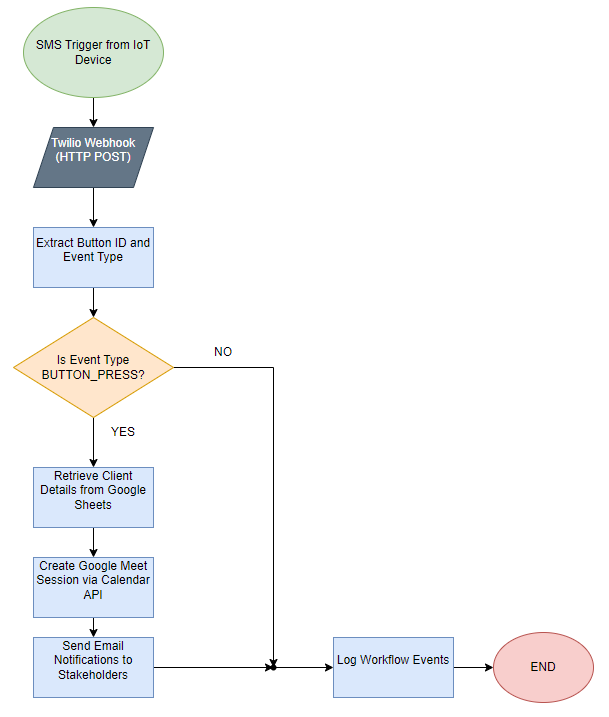
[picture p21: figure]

FIGURE 24: BACKEND CODE FLOW DIAGRAM

The backend workflow begins with the IoT device sending an SMS trigger to a Twilio-

managed phone number. Twilio's webhook forwards this SMS as an HTTP POST request to

the backend’s designated endpoint, where the system extracts the relevant details such as

button ID, event type, and battery health status. Depending on the event type, the backend takes different actions. For a button press event, it retrieves client data from Google Sheets

using the button ID, schedules a Google Meet session via the Google Calendar API, and

sends email notifications containing meeting details to clients and team members. For a

battery health event, the system logs the information without scheduling a meeting, providing

a comprehensive log for monitoring purposes.

The backend’s modular structure ensures streamlined operations. The calendar_v1.py

module manages Google Calendar interactions, authenticating with Google APIs to create

events that include Google Meet links, predefined durations, attendee lists, and reminders.

The sheets_v1.py module facilitates seamless integration with Google Sheets, allowing

dynamic data retrieval and updates. It supports reading client information, appending SMS

logs, and managing large datasets efficiently. The sms.py route processes incoming SMS

data from Twilio, determines the event type, and triggers appropriate actions, such as meeting

scheduling or logging battery health. The authenticator.py service simplifies API

authentication, ensuring secure and uninterrupted access to Google services.

Scalability and reliability are key features of the backend. It incorporates

comprehensive error handling to manage API failures, network issues, and unexpected data

formats. Monitoring tools provide insights into system performance, ensuring timely

detection and resolution of anomalies. Redundancy in critical components minimizes

downtime, making the system robust and efficient for real-world applications.

Setting up the backend requires enabling Google Sheets and Calendar APIs in the

Google Cloud Console and securely storing API credentials in a JSON file. The application is

configured through a .env file containing essential environment variables, such as API keys

and Google Sheet IDs. The repository is easily installed by cloning the project and running

the app.py file to launch the Flask server. This setup ensures a streamlined deployment

process, enabling rapid implementation of the IoT emergency button system.

By automating repetitive tasks, such as meeting scheduling and email notifications, the

backend significantly enhances the responsiveness and reliability of the emergency button

system. Its integration with powerful tools and APIs ensures that the system remains

adaptable and scalable, ready to handle growing demands and evolving use cases. This

backend is a testament to the efficiency of modular design in creating a high-performance,

user-centric solution.

Here’s a step-by-step explanation of the code:

### 2.3.1. Modules:

init Module

- Purpose: Acts as an initializer, importing and exposing key modules.
- Key Elements:
- set_calendar from calendar_v1 is renamed to calender_invite.
- GoogleSheets is imported from sheets_v1.
- __all__ makes calender_invite and SheetService available for external

imports.

calendar_v1 Module

- Purpose: Manages Google Calendar events.
- Key Function:
- set_calendar(invitees: list[str]):
1. Authentication:
- Uses GoogleAuthenticator with credentials from the config

(CREDENTIAL_FILE).

- Grants access to the Google Calendar API

(CALENDER_TOKEN).

2. Event Creation:
- Sets an emergency meeting (summary, location, description).
- Calculates event start_time and end_time (1-hour duration).
- Formats invitees as attendees ([{'email': email}]).
- Configures reminders (email: 30 mins, popup: 10 mins).
- Adds Google Meet link via conferenceData.
3. API Call:
- Uses the Calendar API to insert the event into the user's

primary calendar (service.events().insert).

sheets_v1 Module

- Purpose: Manages Google Sheets operations.
- Key Elements:
- google_spreadsheet():
- Authenticates and returns credentials and a Sheets service instance.
- GoogleSheets Class:
- Initializes with a SPREADSHEET_ID (from the config).
- Exposes creds and service as properties.
- Methods:
- get_total_rows(sheet_name): Fetches the total number of rows

in a sheet.

- read_data(sheet_name, range_): Reads a specific range of data.
- read_all_data(sheet_name): Dynamically reads all data from a

sheet.

- write_data(sheet_name, range_, values): Writes data to a sheet.
- append_data(sheet_name, values): Appends data as new rows.

### 2.3.2. Routes

init Route

- Purpose: Imports and exposes the sms_bp Blueprint for routing.

sms Route

- Blueprint: /emergency-button
- Key Route:
- /inbound-emergency:
1. Handles POST requests.
2. Extracts SMS Data:
- Parses From, To, Body from the request form.
- Splits the Body into button_id, event_type, and battery_health.
3. Logs SMS Data:

- Appends the data to the SMS Logs sheet via

GoogleSheets.append_data.

4. Checks Event Type:
- If not "BATTERY_HEALTH", reads the Client Info sheet for

the associated email using the button_id.

- Sends calendar invites (calender_invite) if email(s) are found.
5. Returns a JSON response:
- Indicates success (200) or failure (500).

### 2.3.3. Services

init Service

- Purpose: Creates and configures the Flask app.
- Key Elements:
- Loads config (ProductionConfig or DevelopmentConfig based on the

environment).

- Registers the sms_bp Blueprint.

config Service

- Purpose: Manages configuration using .env variables.
- Key Classes:
- Config: Defines shared configurations (SHEET_TOKEN,

CALENDER_TOKEN, CREDENTIAL_FILE, GOOGLE_SHEET).

- DevelopmentConfig: Enables debugging.
- ProductionConfig: Disables debugging and testing.
2.3.4. Application

app.py

- Purpose: Entry point for the application.
- Key Elements:
- Creates the Flask app using create_app().
- Runs the app with debug=True on port 3000.

2.3.5. Requirements

Dependencies include:

- Flask: Web framework.
- Google APIs: Authentication and API interaction libraries (google-auth, google-api-

python-client).

- dotenv: For environment variable management.

Flow Summary

1. SMS Handling:
- Receives SMS via /inbound-emergency.
- Logs SMS in the SMS Logs sheet.
- If event_type is not "BATTERY_HEALTH", it sends calendar invites to

associated emails.

2. Calendar Invite:
- Sets a 1-hour meeting via Google Calendar API with reminders and a Google

Meet link.

3. Google Sheets:
- Logs and retrieves data from specific sheets dynamically.

This system enables seamless SMS logging and meeting scheduling with Google

services integration.

### 2.4 3D Modeling

The button was designed in Fusion 360. The design process of the product evolved

through several iterations, each addressing functional and aesthetic challenges. The journey

began with inspiration from an AI-generated concept image shown in figure x.

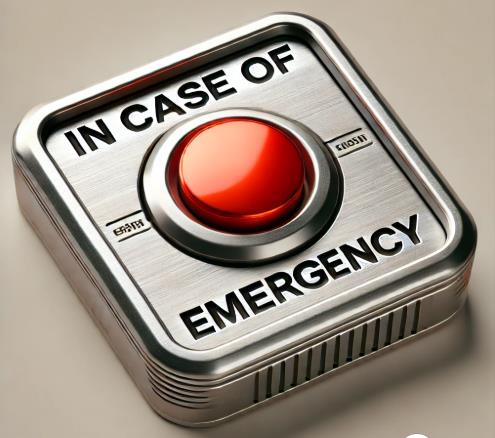
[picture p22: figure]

FIGURE 25: AI CONCEPT IMAGE OF THE BUTTON

The initial vision focused on creating a compact, striking box with a bold design. This

resulted in the first version (V1), which featured a 12x12 cm box. However, it was quickly

scaled down to 7x7 cm to keep things compact. V1 included a 3D-printed red button mounted

on a push button, an acrylic top engraved with “In Case of Cyber Security Emergency,” and

the SIM800L V1 module, chosen for its compact size. This version was powered by LiPo

batteries to maintain a slim profile. V1 is shown in figure x.

FIGURE 26: BUTTON 3D MODEL V1

While promising in concept, V1 encountered significant challenges. The 7x7 cm

dimensions severely limited internal space, making it difficult to fit all components. For

example, the antenna could not be housed internally and had to be mounted externally,

resulting in an undesirable "bomb detonator" appearance. The LiPo batteries required

additional circuitry, such as a TP4056 charging module with a USB-C connector and a

manual switch, which further constrained the layout and added undesirable holes in the box.

The SIM800L V1 module also proved unreliable, frequently losing connectivity. Moreover,

screw holes were added to mount the PCB internally, with precise clearances to ensure a

secure fit, but the overall design felt too small and impractical.

To address these issues, V2 introduced significant changes. The box size was increased

to 9x9x7 cm, to accommodate larger batteries (18650) and to fit all components comfortably.

The switch to three 18650 batteries enhanced the circuit’s battery life significantly (more than

a year) and simplified maintenance. Instead of requiring internal charging circuitry, the

batteries could now be easily swapped out if ever needed, ensuring long-term usability. The

unreliable SIM800L V1 module was replaced with the SIM800L V2, which, although

slightly larger, was far more reliable. The 3D-printed button was replaced with a

professional-grade Sanwa arcade button, offering a polished red finish and a satisfying tactile

response. Despite these improvements, the V2 design was bulky, plain, and did not meet the

aesthetic expectations of the Red Crew. The V2 version is shown in figure x:

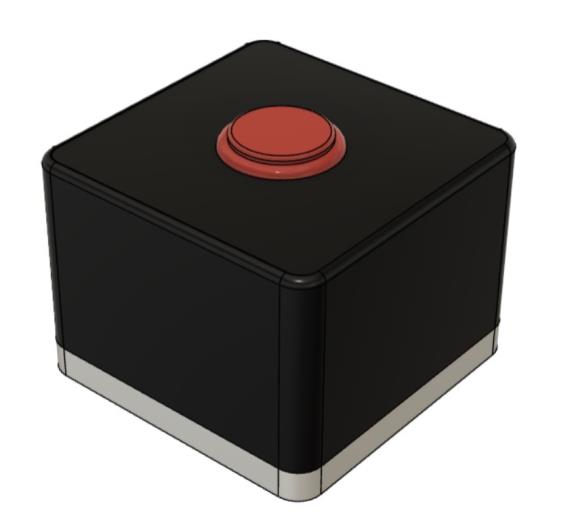
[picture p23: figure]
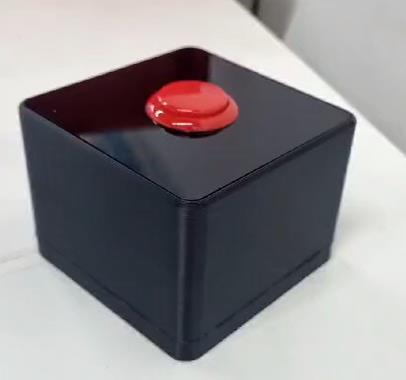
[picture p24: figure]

FIGURE 27: BUTTON 3D MODEL V2

In V3, the focus shifted to enhancing the design's visual appeal while maintaining

functionality. The button’s design should be a design with purpose. Drawing inspiration from

arcade machines and cyberpunk aesthetics, an angled element to the button was added.

Initially, all edges were filleted to soften the design, but this approach gave the box an

unattractive, overly rounded appearance. V3 is shown in figure 28.

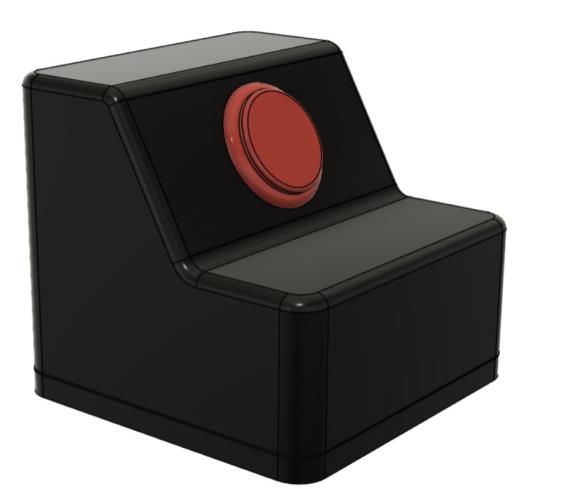
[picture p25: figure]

FIGURE 28: BUTTON 3D MODEL V3

In V4, a triangular hood angled above the button was introduced. This design element

was discovered accidentally through a glitch during modeling but was retained for its unique

look. The fillets were replaced with chamfers and sharp, triangular features, achieving a

sleek, modern, and edgy style. V4 is shown in figure 29.

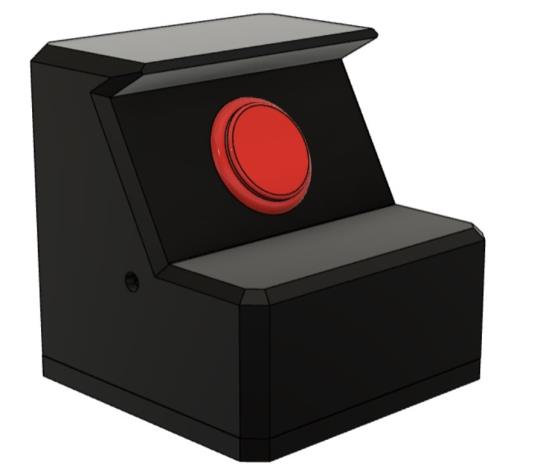
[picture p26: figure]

FIGURE 29: BUTTON 3D MODEL V4

Further refinements were introduced in V5, maintaining the chamfers and triangular

aesthetics while optimizing the hood’s angle for balance and visual appeal. However, the

matte 3D-printed finish of earlier iterations still felt underwhelming. To address this, V5

introduced a hybrid approach: black acrylic covers mounted on a 3D-printed skeleton. This

combination elevated the product’s look, making it feel more luxurious and professional.

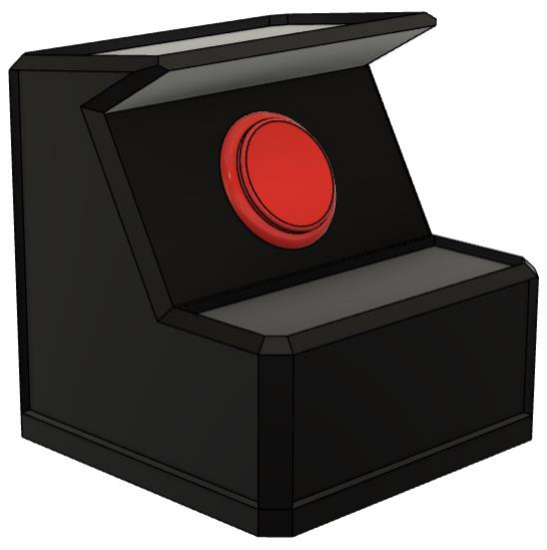
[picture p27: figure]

FIGURE 30: BUTTON 3D MODEL V5

The acrylic covers give the design a polished and glossy look. They are laser cut on

2.5mm back acrylic. 2mm also works fine. The covers are shown in figure 31.

FIGURE 31: ACRYLLIC COVER LASER CUT DESIGN

The evolution from V1 to V5 reflects a balance between functionality and design.

Starting with a compact but impractical box, the product matured into a robust, visually

appealing device that meets technical requirements while embodying an edgy and modern

cyber design.

The full product assembly is done on fusion 360 showcasing the internals and assembly

of the product. The PCB is mounted with 4 M3 screws to the base. Underneath the PCB lie

the 3 lithium batteries with cables extending from the battery cases to the PCB. The

electronics also fit with enough clearance to avoid touching the box cover. This is shown in

figure. X

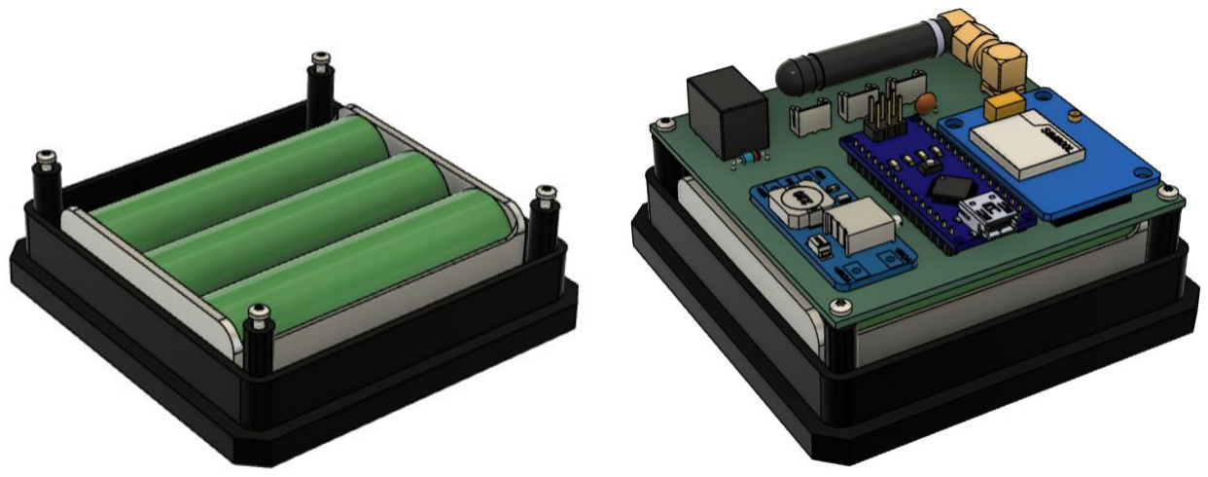
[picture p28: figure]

FIGURE 32: ASSEMBLED 3D MODEL WITH CROSS SECTION

### 2.5 Manufacturing and Setup Instructions

The manufacturing process and setup of the IoT emergency button device are designed

to be scalable and efficient, ensuring high-quality output while keeping costs and complexity

manageable. Two versions of the enclosure are provided: one fully 3D-printed and the other

with a combination of 3D-printed components and laser-cut acrylic covers for a premium

finish.

1. 3D Printing and Laser Cutting

The enclosure and internal mounts are printed using PLA with a layer height of 0.2mm

for precision. A 20% infill is recommended for structural stability while keeping weight

manageable. The enclosure consists of the main box, and the main base. internal mounts. The

main box has 2 versions. The fully 3D printed version and the acrylic version. If the acrylic

version is printed, make sure to laser cut the included covers in 2.5mm black acrylic. Post-

printing, remove any supports and sand the edges for a clean fit. Ensure that all screw holes

and slots align as per the design specifications. Any local 3d printing service can print this

with no problem. For Aesthetics try to print the button in black.

2. Arduino Hardware Modifications

To maximize power efficiency of the Arduino, some hardware modifications need to be

done to achieve the 1- year battery life goal. Without hardware or software modifications the

Nano measured to draw about 18mA of current. Note that the circuit will stay on for a long

time. This configuration gives us:

Capacity = Amps(A) ∗ Hours(H)

Hours =

Capacity
A

=

2500maℎ
18ma

= 138.8 ℎours = 5 .75 days

Sleep mode alone brings down the Arduino’s consumption to around 8mA (measured). If

we are using a 2500mah Battery the lifetime will be:

Hours =

Capacity
A

=

2500maℎ
8ma

= 312.5 ℎours = 13.02 days

The always on power onboard LED draws around 5 mA. Removing it as seen in figure x will

give us:

Hours =

Capacity
A

=

2500maℎ
2ma

= 416 ℎours = 17 .33 days

The last modification to be done is to remove the onboard voltage regulator. As the

Nano has a ATMega328p microcontroller, it can run on 3.3 volts comfortably. It should have

no problem running on 3.7 volts or higher. The voltage regulator draws unnecessary current

so it must be removed. The results of this final modification gave outstanding results which

will be seen in the results section. The modifications are seen in figures X and X. The TX

LED might also be on if serial communication is taking place so its best to remove it as well.

They can be removed with needle nose pliers or wire cutters. They can also be desoldered.

FIGURE 33: POWER LED TO BE REMOVED

FIGURE 34: ONBOARD VOLTAGE REGULATOR TO BE REMOVED

3. PCB Manufacturing and Soldering

The PCB layout is created using KiCad, adhering to an 8x8 cm size. Mounting holes for

M3 screws are included for secure attachment. Upload the Gerber files provided to a service

like JLCPCB or PCBWay for production. Even a local PCB manufacturer can do this as it’s a

simple single layer board. Make the PCB with silkscreen, solder mask, and tinned pads for

highest quality.

Once the PCBs arrive, solder the components onto the board, starting with the MT3608

boost converter using male pin headers as shown in figure 23. If the header comes with many

heads break 4 individual pins to fit them in the slot for the mt3608 and solder them carefully.

Follow this with other components like the relay, diode, Arduino, and JST connectors.

The Arduino Nano is powered by a single 18650 lithium-ion battery. Its connector is

labeled as power 1, The two-cell holder is wired in parallel for the SIM800L module,

ensuring sufficient current delivery. Its connector label on the PCB is known as power 2.

Solder JST connectors for the batteries, ensuring the correct polarity by verifying the color-

coded wires and PCB layout. Mount the Sanwa button to the acrylic button cover or 3d

printed button cover using the orange screw that comes with the button. The button polarity

does not matter as the button is simply a switch. The button JST connector is labeled as

“Button” on the silkscreen.

Solder the relay and its accompanying 1N4007 diode. Position the diode across the relay

terminals to protect the circuit from voltage spikes. Make sure to check the polarity of the

diode because reversing the diode polarity will lead to instabilities. The silkscreen should

show the correct orientation. Mount the Sanwa button to the acrylic or 3d printed button

cover using the included orange screw. Solder wires to the button, and battery cases measuring and trimming to avoid excess length. Use heat shrink tubing to secure connections

and prevent short circuits. Do this for all connections.

4. Arduino Program Setup

This section provides detailed instructions to set up the Arduino part of the IoT

emergency button system, ensuring it is ready for deployment. Follow these steps to

configure the device, customize it for specific users, and debug the system if necessary.

Using Arduino IDE, Upload

“Emergency_Meeting_Scheduling_Device_Arduino_Code_Working” sketch BEFORE

connecting the batteries via its micro-USB port. You can upload the code while the batteries

are installed but it is safer to install them later to avoid risking damaging your hardware.

Open the Arduino IDE and navigate to the SendSMS() function in the code.

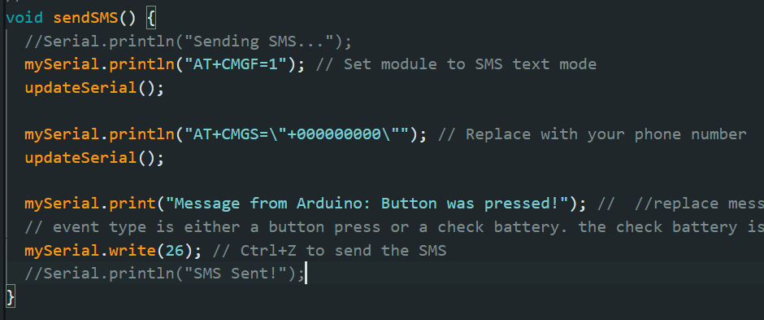
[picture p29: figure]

FIGURE 35: CODE TO BE MODIFIED

Replace the placeholder phone number +000000000 with the Twilio Server phone

number. You can use any number if using for SMS purposes only. This number that is

inserted is the number of the recipient that will receive the SMS.

mySerial.println("AT+CMGS=\"+000000000\""); // change to recipient number.

Update the Button ID variable to assign a unique identifier for the device, useful in

systems with multiple buttons.

String ButtonID = "001";

Replace "Message from Arduino: Button was pressed!" with

"001,BUTTON_PRESS,100%" when using with server to send emails. Do not put spaces in

this message copy and paste it as is. Change Client ID if there are more than 1 buttons. Any

message can be sent if not using the device it with the server.

mySerial.print("Message from Arduino: Button was pressed!");

mySerial.print("001,BUTTON_PRESS,100%");

The event type is either a button press, or a check battery. the check battery event is for

future improvements not included in this code, where the Arduino can monitor the battery

voltage. another code is provided for monitoring battery health.

To enable debugging, uncomment the Serial.print lines in the code to enable debugging

through the Arduino Serial Monitor. This allows real-time feedback on operations such as

network connectivity, SMS sending, and button presses. They are by default disabled to

avoid setting the Arduino’s TX light on constantly and to make the code run faster. Use the

Serial Monitor in the Arduino IDE to observe system behavior during testing.

5. Assembly

Place the fully charged 18650 batteries into their holders (should read 4.2 volts at

maximum charge) and connect them to the JST connectors. DOUBLE-CHECK THE

BATTERY POLARITY BEFORE POWERING THE CIRCUIT. In this version, there is no

reverse polarity protection in this version so please be careful when plugging the batteries.

Then, insert the battery holders in the base of the “Main Base” part, then secure the PCB to

the base of the enclosure using four M3x10 screws. Ensure all components have adequate

clearance. Attach the button cover to the main box through the dedicated square hole and

glue it in place with super glue, ensuring it does not interfere with the internal components.

Attach the box housing by simply sliding it in with the friction-fit design. Such that there is

no play and the base with the batteries won’t slide out easily even with heavy shaking. Ensure

all external components, such as the SMA antenna, are securely mounted and soldered in

place. The assembly is shown as an animation provided in the README file in the

repository.

Use an active SIM card with SMS capabilities. Insert the SIM card into the SIM800L

module's slot, ensuring the correct orientation as indicated on the SIM800LV1 module as

shown in figure 36. The same applies for the SIM800L V2. The sim card slot is on the side of

the PCB making it accessible even if soldered in place. Any 2G Micro SIM card will work

perfectly. If the sim card is too small use a SIM card adapter for it to fit on the module. The

proper way to insert the SIM card is typically engraved on the surface of the SIM socket.

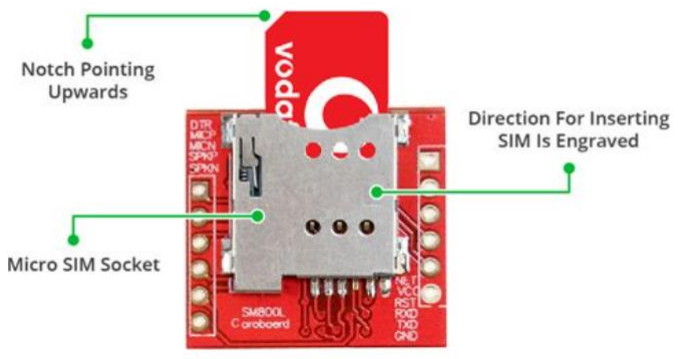
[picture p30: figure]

FIGURE 36: SIM CARD INSERTION ORIENTATION.

To Finalize the SIM Connections, screw in the external antenna to the board to enhance

GSM signal reception, especially in areas with weak signals. Make sure the antenna is

mounted and soldered in properly to the SMA connector and that the antenna cable is

plugged into the SIM800L IPX slot and tucked inside the edges of the PCB.

## 3. RESULTS AND DISCUSSION

The results section presents the outcomes of the design, development, and testing

processes for the IoT emergency button system. This device was evaluated based on its

functionality, reliability, and adherence to project objectives. The results encompass all

critical aspects, including the electronic circuitry, software implementation, 3D-printed

housing, and overall system performance under various test conditions. This section

highlights the device’s ability to meet the outlined requirements, such as long battery life,

seamless GSM-based communication, and robust design. Additionally, challenges

encountered during the development phase are addressed, along with their resolutions, to

provide a comprehensive assessment of the project’s success.

FIGURE 37: FINAL BUTTON 3D PRINTED PROTOTYPE DESIGN

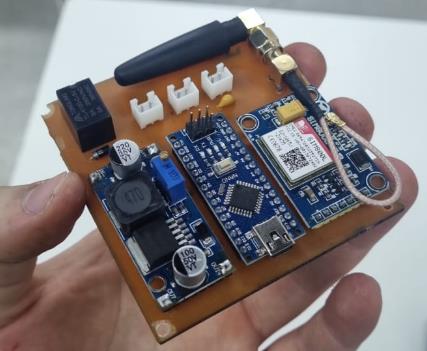
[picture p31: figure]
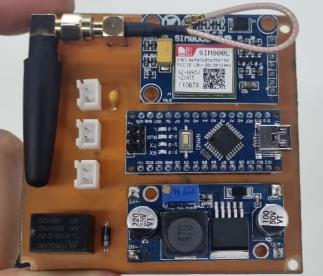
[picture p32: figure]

FIGURE 38: ASSEMBLED PCB

Note that the boost module in figure 38 is the XL6009 Boost module but was later

swapped to the MT3608 because according to the data sheet of the XL6009, it only boosts

voltages starting from 5 volts and above even though it did work fine in this application but it

is better to stick to the manufacturers recommendations to prevent future issues. The MT3608

is better suited for such purposes as indicated in reference [4] as it supplies up to 2 amps in

theory and works well with 3.7-volt batteries. It is advisable to add a 470 uF capacitor at the

VOUT terminals of this module. To minimize noise. The included PCB schematic is updated

to accommodate the MT3608.

FIGURE 39: DIY PCB TRACES

Due to time constraints, the PCB was manufactured in house, thus, the result is a crude

looking PCB that works great. It’s advisable to manufacture the PCB in a professional

environment by using service providers like PCB way.

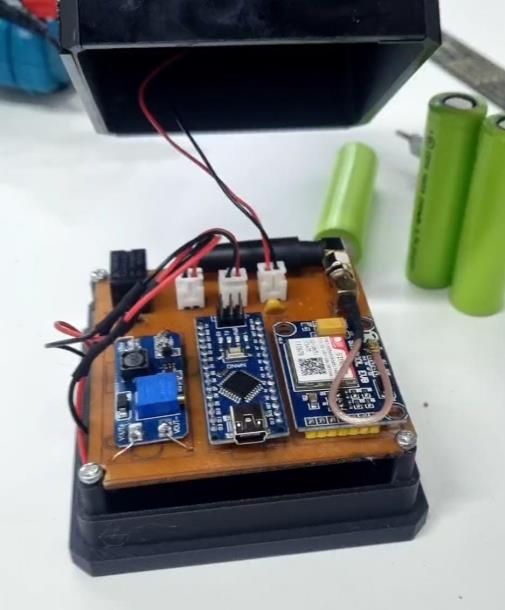
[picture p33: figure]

FIGURE 40: FINAL ASSEMBLY OF THE DEVICE

Once all connected and assembled, all is left is to press the button. Once the button is

pressed, the Arduino wakes up from sleep mode, the relay coil is energized, the Arduino

onboard LED flashes, and an audible click should be heard from the relay and the sim

module turns on. The SIM module should start to blink once every 1 seconds for about 10

seconds before connecting to the network. Once it connects to the network, the SIM module

should blink once every 3 seconds. More information on how the sim module should behave

is shown in reference [x]. Then, a few seconds will pass waiting for the module to stabilize

which then leads to the message will be sent. Once the message is sent, the onboard LED will

flash for half a second, the SIM module will stay on for 2 seconds to ensure the proper

delivery of the message and then it will turn off. The relay will tick again de-energizing the

coil, switching the relay contact, and turning off the module. The functioning of the circuit

can be viewed in the Arduino IDE Serial monitor by uncommenting the Serial.print

functions. The working result is shown in figure 41

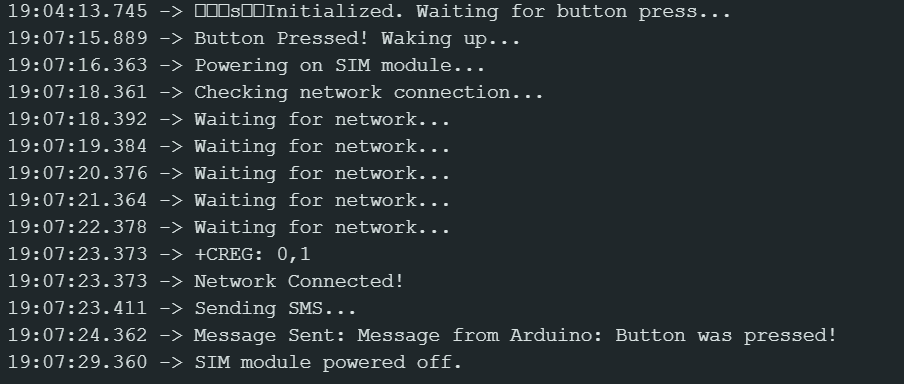
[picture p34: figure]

FIGURE 41: SERIAL MONITOR SHOWING THE SENDING OF THE SMS AND THE WORKING OF THE DEVICE

FIGURE 42: RIGOROUS TESTING ON MULTIPLE RECIPIENTS WHO RECEIVED MESSAGES FROM THE ARDUINO WHEN THE BUTTON WAS PRESSED

The button was tested hundreds of times to make sure it works properly. A trouble

shooting guide is provided in the next section. The battery monitoring function was a test

later to be discussed.

Now that the button successfully sends SMS messages, it can be hooked to the server.

Practically, the button is just a message sending device. Any phone can interact with the

server if the right SMS is sent to the right number. Simply replace the “Message from

Arduino: Button was pressed!” with the button id, event type, and battery health percentage.

And make the recipient of the message the server recipient phone number in Twilio. This

enables the device to communicate with the server and make it work properly. The event type

in this project version is limited to BUTTON_PRESS but in the future can be modified to

monitor the battery percentage with the BATTEY_HEALTH event. Figure 43 shows the

SMS logs linked to the google sheet document showcasing all the events that took place.

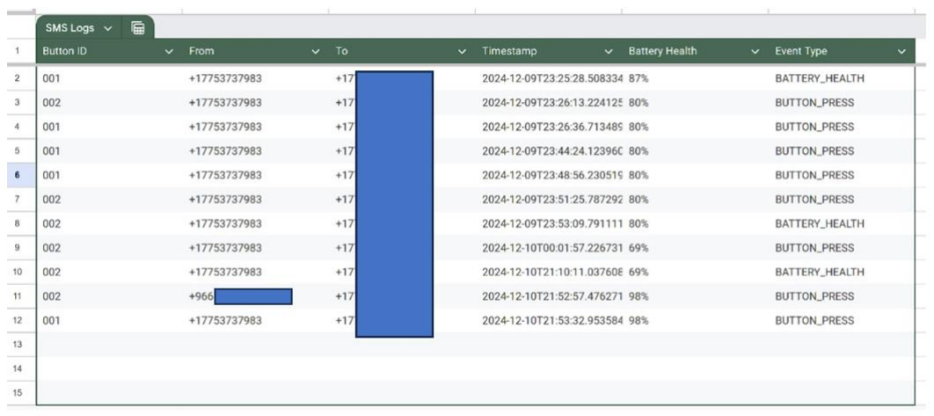
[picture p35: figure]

FIGURE 43: SMS LOGS OF ALL MESSAGES RECEIVED TO THE SERVER AND THE EVENT TYPES

Different numbers were tested from different countries. They all worked except

attempting to send the number from Lebanon as sending SMS messages from Lebanon to

international numbers or American numbers do not work, which is unfortunate. However

other numbers from different countries such as Twilio’s virtual number and a Saudi Arabian

number worked fine. It is preferred to register and verify in Twilio, a local number for the

server from the country that the button will be deployed in.

When the event type is received as BUTTON_PRESS, the code will check the button

ID and compare it with the client ID retrieved from the Client data table shown in figure 44

which contains the client’s data such as emails, name, and phone number. This data is

initially filled out by the client or the company using a google forms document shown in

figure x which when submitted, automatically saves the information in the client data table,

each client has a unique button ID, list of emails, name, and telephone number, which is used

by the server to know to which client to send the emails to.

FIGURE 44: CLIENT DATA TABLE

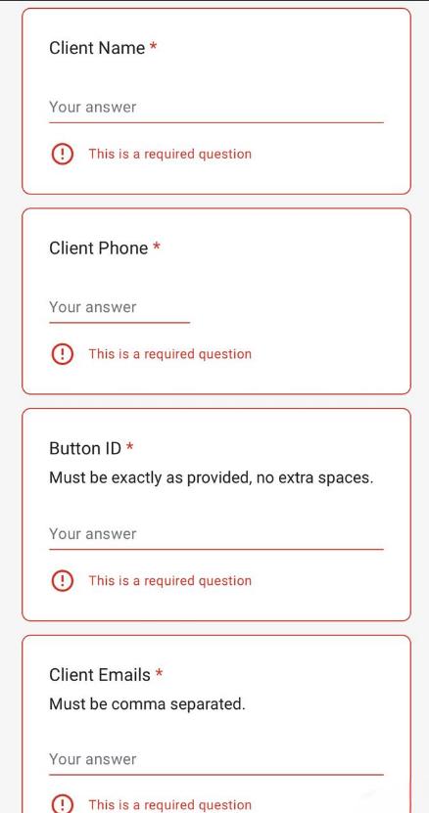
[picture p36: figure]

FIGURE 45: GOOGLE FORM TO FILL IN CLIENT DATA

FIGURE 46: RECEIVED INSTANT MEETING EMAILS VIA GOOGLE CALENDAR

During Testing, 2 SMS messages were sent at different times each with a different

button ID which is why 2 emails were received at different intervals. The same Button ID can

handle multiple emails. This can be done by filling out in the google form multiple emails

separated by a comma. This was done in other tests successfully, video links showing this

will be shown in the repository.

Finally, one of the goals was to make a device with a battery that can last up to a year.

The Arduino has its own independent power source. It is important to calculate the Arduino’s

battery span and the SIM800L’s battery life as they are 2 different power sources. By

implementing sleep mode to reduce power consumption in standby mode, switching off the

SIM module completely when not using it, and modifying the Arduino’s hardware, the result

is a device that when in standby mode consume only 80 micro-Amps. Assuming the button is

pressed once per day, the Arduino wakes up from sleep mode and draws about 12 mA for 1

minute to trigger the circuitry. Assuming the button is pressed once per day and the Arduino

itself has a single 2500mAh battery. The result for the Arduino:

Standby current = 80μA = 0.08mA

Button Press current = 12mA

1 minute =

1
60 ℎours = 0.0167

ℎours
day

Energy consumption during button press (1 minute per day):

milli Amp ℎours
day | = 12ma × 0.0167

ℎours
day = 0.2004

mAℎ
day

Energy consumption during Standby Mode (approximately 24 hours per day):

milli Amp ℎours
day | = 0.08ma × 24

ℎours
day = 1.92

mAℎ
day

Total Arduino Consumption per Day:

Total Daily Consumption = Standby + Button Press = 1.92 + 0.2004 =

2.12maℎ
day

Arduino Battery Life =

| 2500mAℎ
| 2.12 mAℎ
| day = 1179.24 days = 3.23 years

As for the SIM800L, its switched completely off by the relay using the normally open

contact most of the day. The sim module turns on for 1 minute every day assuming a daily

single button press. When on, the SIM800L draws about 200mAh for 1 minute then shuts off.

The SIM800L has its own dedicated power supply (2x18650 2500mAh batteries in parallel

totaling 5000mAh of capacity).

SIM800L Standby current (off) = 0mA

Button Press current = 200mA

1 minute =

1
60 ℎours = 0.0167

ℎours
day

Energy consumption during button press (1 minute per day):

milli Amp ℎours
day | = 200mA × 0.0167

ℎours
day = 3.34

mAℎ
day

Energy consumption during Standby Mode (approximately 24 hours per day):

milli Amp ℎours

day | = 0mA × 24 ℎours
| day = 0

mAℎ
day

Total SIM800L Consumption per Day:

Total Daily Consumption = Standby + Button Press = 0 + 3.34 =

3.34mAℎ
day

SIM800L Battery Life =

5000mAℎ
3.34 mAℎ
day

= 1497days = 4.1 years

These results exceeded completely the 1-year goal with room to spare. However, it is

important to regularly check and maintain the device for best performance, and to use high

quality batteries and make sure they’re fully charged before using. Practically speaking, the

battery life is less than the theoretical calculations but even with a 50% margin of error

(which is unlikely) the lifespan should meet our requirements. Figure 47 shows the Arduino’s

outstanding 80 microamp current draw at 3.7 volts in figure x. The power supply couldn’t

even detect the current draw.

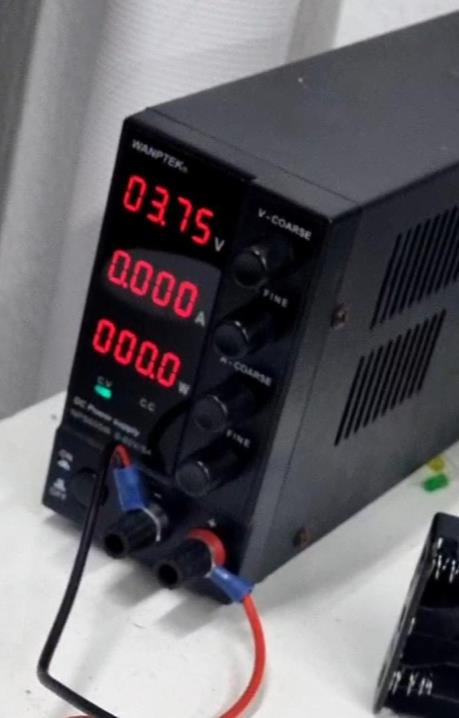
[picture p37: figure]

FIGURE 47: ARDUINO POWER CONSUMPTION DURING STANDBY MODE

3.2 Troubleshooting Guide

This troubleshooting guide provides a comprehensive overview of common hardware

issues encountered during the development and operation of the IoT emergency button

device, along with detailed solutions. By addressing problems systematically, users can

ensure the device operates reliably and meets design expectations.

The SIM module is often the primary source of challenges. If the module fails to

connect to the network, it may respond to AT commands but not register on the network.

This could be due to an inactive SIM card, unsupported GSM bands, antenna issues, network

access denial (discussed later), or poor signal strength. To resolve this, ensure the SIM card is

active and test it in a mobile phone to verify network connectivity. Replace or reposition the

antenna to enhance reception, and verify that the SIM module complies with local

regulations. Check the SIM card if it is inserted in the correct orientation as discussed

previously.

Another common SIM-related issue is the inability to send SMS messages. This can

occur due to improper configuration, such as the module not being set to text mode, invalid

phone number formatting, insufficient balance on the SIM card, or power fluctuations. To fix

this, configure the module to text mode using AT+CMGF=1, ensure phone numbers are

correctly formatted, and verify the SIM card’s balance. Adding bypass capacitors near the

SIM module can stabilize voltage during high current draws. A 470uF capacitor should work

fine. In normal cases this isn’t needed.

The button, a critical input component, can also exhibit problems. If false presses are

detected, this is often due to electrical or mechanical noise. Adding a 0.1µF capacitor across

the button terminals or implementing software debouncing in the Arduino code can mitigate

this issue (a debouncing capacitor is included in the PCB design) Inspect and re-solder

connections and configure the button pin as INPUT_PULLUP in the code to ensure a stable

signal.

Power supply issues are the most common issues and can manifest as the Arduino

failing to boot or the SIM module overheating. Incorrect battery connections (reverse

polarity), insufficient current supply, low battery voltage (18650 below 3.5 volts) or voltage

mismatches can cause these problems. Ensure proper battery polarity and securely connect

JST connectors. For the SIM module, confirm the boost converter outputs a stable 5V and

can supply at least 2A. Replace faulty components if overheating persists. Check solder joints to make sure components are secure and properly soldered to the pcb pads and traces. Inspect

the PCB for trace issues if made in house.

For debugging, uncomment the Serial.print lines in the code to monitor real-time operation

through the serial monitor. Use a dedicated test sketch (included in the repository) to verify

SIM800L functionality and a multimeter to measure current draw during operation and sleep

mode. Periodically inspect the PCB for clean and secure solder joints, ensure proper

orientation of polarized components, and confirm the polarity of all connectors based on the

PCB layout and wire color scheme. Additionally, position the antenna to minimize signal

interference and maximize network connectivity. The sim800L should draw about 100-

200mA when searching for a network then the current should drop to around 40mA once

connected. Reference [1] has more information about troubleshooting the SIM800L.

When debugging using the serial monitor here are some of the important network

connection AT responses and errors encountered. When working with the +CREG command

on the SIM800L module, you may encounter various registration status codes, each

indicating different network registration states. Here's a troubleshooting guide for each:

+CREG: 0,0 (Not registered, no network search): This indicates that the module is not

registered to any network and is not attempting to find one. Common causes include a faulty

or missing SIM card, a SIM card with a PIN lock (which needs to be disabled), or an

insufficient signal in your area. It can also happen if the SIM card is not activated or is

incompatible with the module.

+CREG: 0,1 (Registered, home network): This means the module is successfully registered

on the home network and can send/receive data. If you're not seeing this status, check if the

SIM is inserted correctly, and ensure the module has a stable power supply and good signal

strength.

+CREG: 0,2 (Registered, roaming): The module is connected to a network while roaming.

This could be normal if you're in an area where your home network's coverage doesn't reach,

and you're connected to a partner network. Ensure that roaming is enabled on your SIM card,

as some carriers disable roaming by default, and you may need to contact your provider to

enable it.

+CREG: 0,3 (Registration denied): This indicates that the network has rejected the module's

registration attempt. Causes could include a network incompatibility (e.g., if you're using a

2G-only SIM800L in an area where 2G networks are no longer available), network

congestion, or issues with the SIM card (e.g., a suspended account). Ensure that your SIM

card is active and supports the necessary network bands.

+CREG: 0,4 (Unknown registration status): This means that the module couldn't determine

the registration status, possibly due to network issues, signal problems, or configuration

errors. Common causes include poor or no signal, incorrect network settings, or a

malfunctioning SIM card. Try moving to a different location with better signal, or reset the

module with AT+CFUN=1,1 to force a restart and reattempt registration.

By following these troubleshooting steps, users can address most hardware issues

encountered with the IoT emergency button device, ensuring long-term reliability and

functionality. Regular maintenance, such as inspecting battery connections and testing the

device periodically, can further enhance performance.

### 3.3 Regulatory Considerations for the Device

The deployment of this GSM-enabled device involves critical regulatory requirements

to ensure legal compliance and uninterrupted functionality. Given the nature of GSM

modules like the SIM800L, users must adhere to specific telecommunication laws and

standards to avoid operational issues. This section provides a detailed overview of these

regulations, their importance, and guidelines for registering the device with the local

authorities.

### 3.3.1 Telecommunication Module Registration:

GSM modules, unlike standard consumer phones, require additional steps to be

authorized for use on local networks. Consumer phones are pre-registered with unique serial

numbers (IMEI) recognized by the government, allowing them to connect seamlessly to the

network. GSM modules like the SIM800L, however, are not always pre-registered and

require manual authorization to avoid being flagged as unauthorized devices.

When importing these modules from abroad, the Ministry of Telecommunications

(MoT) of the user’s country must be notified. Failure to disclose and register these modules

can result in the device being temporarily allowed to connect, maybe once only, flagged as unauthorized, and subsequently banned from the network. This scenario caused significant

delays in this project, as unregistered SIM800L modules were flagged and disconnected,

rendering the device non-functional.

### 3.3.2 Vendor Responsibility and Local Purchases

For users purchasing these modules locally, it is essential to confirm whether the vendor

has already registered the modules with the MoT. Some vendors adhere to the necessary

regulations and pre-register the modules during importation, but others do not. Buyers should

verify this information before purchasing. If the modules are not pre-registered, they may

face connectivity issues, including temporary network access followed by a ban due to non-

compliance. Check the functioning of the SIM module at the vendor’s shop by simply

connecting it to power. There is no need to connect TX or RX to check it is connecting to the

network as long as it has a SIM card in it. The light blinking indication timing proves its

connectivity as seen in reference [x].

### 3.3.3 Registration Process for GSM Modules (if needed)

1. Obtain Proof of Purchase: Ensure that you have a valid receipt or invoice from the vendor

detailing the module purchase.

2. Gather Required Documentation: Obtain the datasheet of the GSM module (such as the

SIM800L), which contains technical specifications and can often be downloaded from the

manufacturer's website or referenced in this document [2]. Even this documentation might be

useful.

3. Submit Registration Application: File an application with the local Ministry of

Telecommunications (MoT), including the receipt, module datasheet, and a description of the

intended use of the device.

4. Await Authorization: The MoT will review the application and, upon approval, authorize

the module to connect to the network.

This process ensures that the device complies with local telecommunication laws,

preventing delays and disruptions in its operation.

### 3.3.4 Impact of 2G Network Deprecation

The SIM800L module operates exclusively on 2G networks, which are being phased out

in many countries in favor of more advanced 4G and 5G technologies. This deprecation poses

a risk to the long-term functionality of the device, as it relies entirely on 2G connectivity to

send SMS messages.

Users must confirm whether their local network still supports 2G services and remain

vigilant about future updates from telecommunication providers regarding the discontinuation

of 2G services. In the event of a complete 2G phase-out, the device would require a hardware

upgrade to use newer GSM modules compatible with 4G or 5G networks.

### 3.3.5 Commercial Use Regulations

For commercial deployment, it is critical to understand and adhere to the local

telecommunication and electronic device laws. Commercial use often imposes stricter

requirements, including additional certifications or inspections.

Users must verify:

- Whether the GSM module complies with telecommunication standards.
- If the device design and operation align with electronic safety regulations.
- Any additional licenses required for commercial use.

Safety and Security Considerations

Regulatory oversight of GSM modules exists for security reasons. Such modules can

potentially be misused for malicious purposes, such as remote detonation devices or

unauthorized network access. Ensuring proper registration and adherence to local laws

mitigates these risks and ensures the device operates within the bounds of the law.

The use of GSM-enabled devices like this one comes with specific regulatory

responsibilities. Users are advised to proactively address registration and compliance

requirements before deploying the device. Whether purchasing modules locally or importing

them, proper documentation and adherence to telecommunication laws are critical.

Additionally, keeping abreast of changes in network standards, particularly regarding 2G

phase-outs, is essential to ensure the device remains operational in the future. For users intending to deploy this device commercially, further legal and regulatory checks are advised

to avoid potential liabilities.

### 3.4 Future Improvements and Contributions

This project represents an essential step toward developing a reliable IoT emergency

meeting scheduling device. While the current implementation achieves its primary

objectives, there are numerous opportunities for improvement in both the hardware and

software components. These enhancements will not only refine the product's functionality

but also make it more adaptable to future needs. By making this project open source, the

intention is to encourage collaboration and innovation from the wider community, fostering

continuous development and improvement.

One of the primary areas for enhancement lies in the backend. Introducing robust error-

handling mechanisms would allow the system to recover gracefully from issues such as API

failures, network disruptions, or invalid data submissions. Additionally, a standalone

website can be developed to oversee backend operations, providing a centralized interface

for users to monitor events, configure devices, and manage schedules. To complement this,

a frontend dashboard could present real-time updates on button presses, scheduled

meetings, and system health metrics, significantly improving user experience and

accessibility.

From a hardware perspective, future designs could focus on creating a more compact

and ergonomic enclosure. This would involve optimizing the layout of internal components

such as batteries, the PCB, and the button. Enhancing the PCB design itself is another

critical improvement area. Being one of the project's first PCB iterations, there is room for

better trace layouts, reduced electrical noise, and more efficient use of space. Additionally,

incorporating reverse polarity protection for the batteries would prevent potential damage

from incorrect installation. Including features such as overcharge and deep-discharge

protection would further improve the device's reliability and safety.

Adapting to evolving network technologies is another significant consideration. The

current design uses the SIM800L, which operates on 2G networks. As 2G services are

phased out in favor of 4G and 5G networks, integrating modules compatible with newer

standards will ensure the device remains functional in the long term. Moreover, the battery

monitoring circuit, which utilizes the A0 pin, a 100k resistor, and a custom code, is already included in the repository. Future iterations could improve upon this by incorporating more

precise monitoring ICs to deliver detailed battery analytics.

As an open-source initiative, this project invites developers, engineers, and enthusiasts

to contribute their expertise to overcome existing limitations and introduce new features.

The battery monitoring section and related functionalities, while not elaborated upon in this

report, are available in the repository for further exploration and refinement. By

encouraging open collaboration, the project aims to harness the creativity and skills of the

community, transforming it into a robust, scalable, and highly adaptable product for

emergency meeting scheduling and beyond.

## 4. CONCLUSION

In conclusion, this open-source IoT device represents a significant advancement in

emergency communication solutions, combining simplicity, scalability, and security to meet

the diverse needs of industries ranging from healthcare to corporate environments. With its

user-friendly design, long-lasting performance, and robust security features, the device

promises to revolutionize how urgent meetings are scheduled and coordinated. The open-

source approach not only makes the device accessible to a broader audience but also

encourages collaboration and innovation, allowing for continuous improvement and

customization. By offering a cost-effective, reliable, and flexible solution, this project has

the potential to transform emergency communication practices and enhance operational

efficiency across various sectors.

REFERENCES

[1] SIM800L with Arduino, https://lastminuteengineers.com/sim800l-gsm-module-arduino-

tutorial/ (https://lastminuteengineers.com/sim800l-gsm-module-arduino-tutorial/)

[2]SIM800L Datasheet,

https://www.makerhero.com/img/files/download/Datasheet_SIM800L.pdf

[3]Relay Datasheet, chrome-

extension://efaidnbmnnnibpcajpcglclefindmkaj/https://img.ozdisan.com/ETicaret_Dosya/445

413_4369639.pdf

[4] MT3608 Datasheet, chrome-

extension://efaidnbmnnnibpcajpcglclefindmkaj/https://www.olimex.com/Products/Breadboar

ding/BB-PWR-3608/resources/MT3608.pdf

[5] Arduino Sleep Mode, https://www.instructables.com/A-Guide-to-Putting-Your-Arduino-

to-Sleep/ (https://www.instructables.com/A-Guide-to-Putting-Your-Arduino-to-Sleep/)

[6] Google Calendar API, https://developers.google.com/calendar/api/guides/overview
[7] Twilio API, https://www.twilio.com/docs/serverless/functions-assets/quickstart/receive-

sms (https://www.twilio.com/docs/serverless/functions-assets/quickstart/receive-sms)

APPENDIX A

Arduino working code:

#include <SoftwareSerial.h> #include "LowPower.h"

// Pin Definitions
const int buttonPin = 2; | // Button connected to pin 2
const int mosfetPin = 6; | // MOSFET control pin connected to pin 6
const int ledPin = 13; | // LED for indication
bool buttonPressed = false; // Tracks if button is pressed

String ClientID = "001" // for scalability change the client button if there are many buttons.
// Create software serial object to communicate with SIM800L
SoftwareSerial mySerial(3, 4); // SIM800L Tx & Rx connected to Arduino pins #3 & #4

// Interrupt Service Routine (ISR) for waking up the Arduino
void wakeUp() {
buttonPressed = true; // Set the flag to indicate button press }

void setup() {
// Configure pins
pinMode(buttonPin, INPUT_PULLUP); // Button with pull-up resistor
pinMode(mosfetPin, OUTPUT); | // MOSFET control pin
pinMode(ledPin, OUTPUT); | // LED pin for feedback
digitalWrite(mosfetPin, LOW); | // Ensure MOSFET starts off
digitalWrite(ledPin, LOW); | // Ensure LED starts off

// Begin serial communication
//Serial.begin(9600);
mySerial.begin(9600);

//Serial.println("System Initialized. Waiting for button press..."); }

void loop() {
// Attach interrupt to the button pin for wake-up attachInterrupt(digitalPinToInterrupt(buttonPin), wakeUp, FALLING);

// Enter power-down sleep mode until button is pressed LowPower.powerDown(SLEEP_FOREVER, ADC_OFF, BOD_OFF);

// Wakes up here when the button is pressed detachInterrupt(digitalPinToInterrupt(buttonPin)); // Disable interrupt if (buttonPressed) {
//Serial.println("Button Pressed! Waking up...");
buttonPressed = false;

// Indicate activity with LED digitalWrite(ledPin, HIGH); delay(500);
digitalWrite(ledPin, LOW);

// Power on SIM module
digitalWrite(mosfetPin, HIGH); //Serial.println("Powering on SIM module..."); delay(2000); // Allow SIM module to stabilize

// Check network connection and send SMS
if (waitForNetwork()) {
sendSMS();
delay(5000); // Wait a few seconds after sending the SMS }

// Turn off SIM module
digitalWrite(mosfetPin, LOW); //Serial.println("SIM module powered off.");

// Indicate return to sleep mode digitalWrite(ledPin, HIGH);
delay(500);
digitalWrite(ledPin, LOW);
}
}

// Function to wait for the SIM module to connect to the network bool waitForNetwork() {
Serial.println("Checking network connection...");
for (int i = 0; i < 30; i++) { // Retry up to 30 seconds mySerial.println("AT+CREG?");
delay(1000);
while (mySerial.available()) {
String response = mySerial.readString(); //Serial.println("Network Check Response: " + response);

// Check if the module is registered to the network
if (response.indexOf("+CREG: 0,1") > -1 || response.indexOf("+CREG: 0,5") > -1) {
//Serial.println("Network Connected!");
return true;
}
}
//Serial.println("Waiting for network..."); }
//Serial.println("Network connection failed."); return false;
}

// Function to send an SMS
void sendSMS() {
//Serial.println("Sending SMS..."); mySerial.println("AT+CMGF=1"); // Set module to SMS text mode updateSerial();

mySerial.println("AT+CMGS=\"+000000000\""); // Replace with your phone number
updateSerial();

mySerial.print("Message from Arduino: Button was pressed!"); // //replace message with "001,BUTTON_PRESS,100%" when using with server to send emails. Change Client ID if there are more than 1 buttons
// event type is either a button press or a check battery. the check battery is for future improvements not included in this code, where the arduino can monitor the battery voltage. another code is provided for monitoring battery health.
mySerial.write(26); // Ctrl+Z to send the SMS
//Serial.println("SMS Sent!");
}

// Function to forward serial data for debugging void updateSerial() {
delay(500);
while (mySerial.available()) { Serial.write(mySerial.read()); }
}

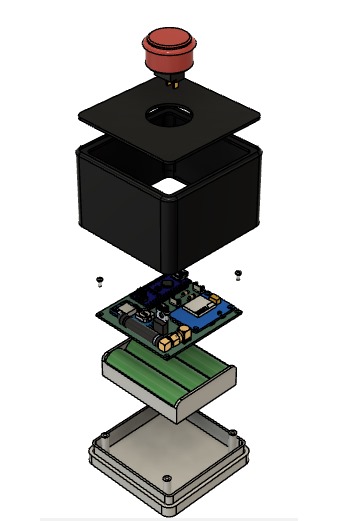
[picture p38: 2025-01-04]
Assets/Assembly.jpg

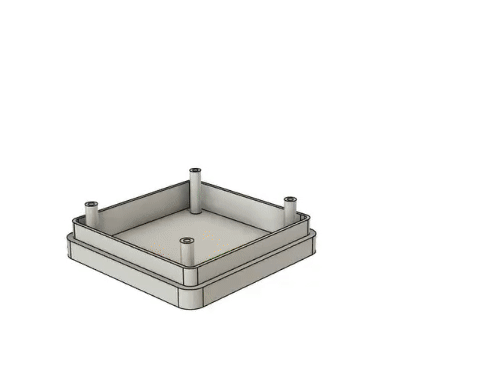
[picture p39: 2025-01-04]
Assets/Assembly.gif

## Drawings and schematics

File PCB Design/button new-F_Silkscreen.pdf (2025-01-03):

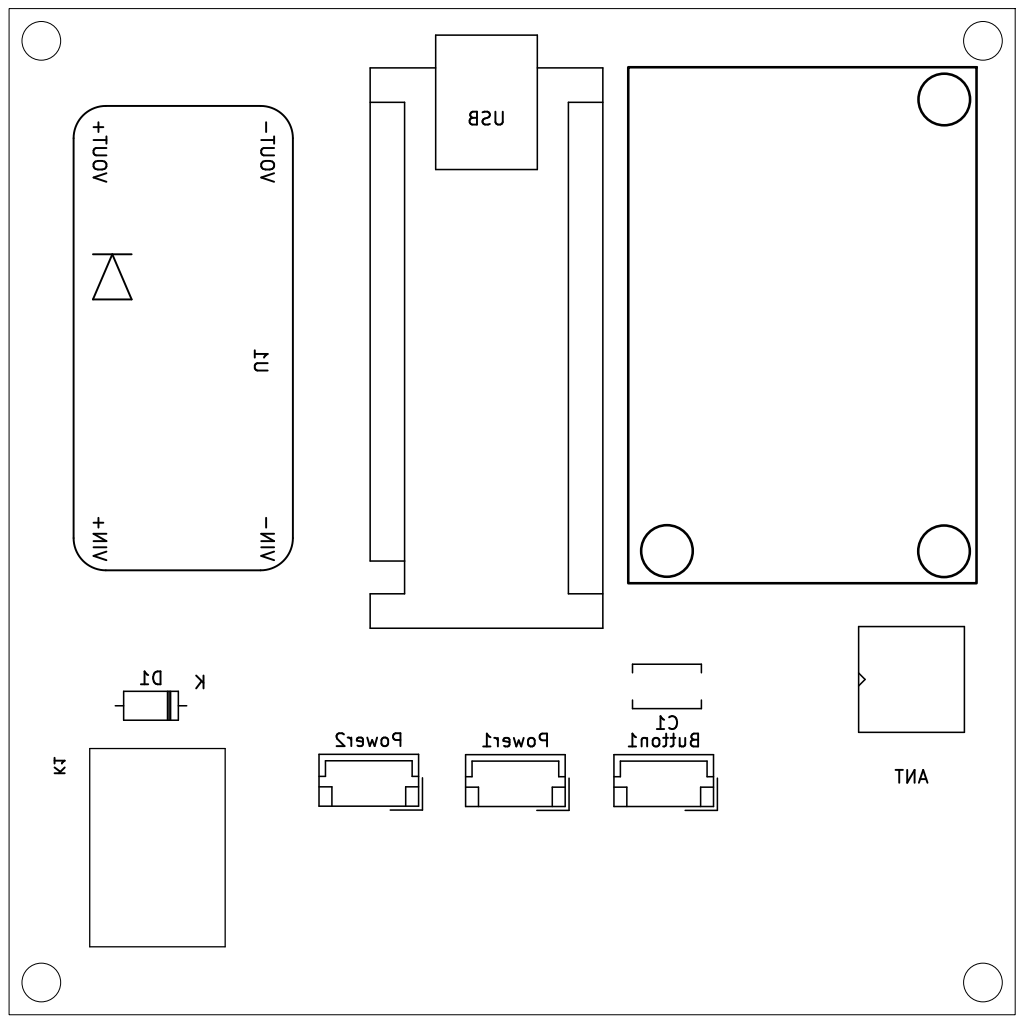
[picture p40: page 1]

Power1 Button1 USB C1 Power2 ANT K1 U1 VIN+ VOUT+ VIN- VOUT-

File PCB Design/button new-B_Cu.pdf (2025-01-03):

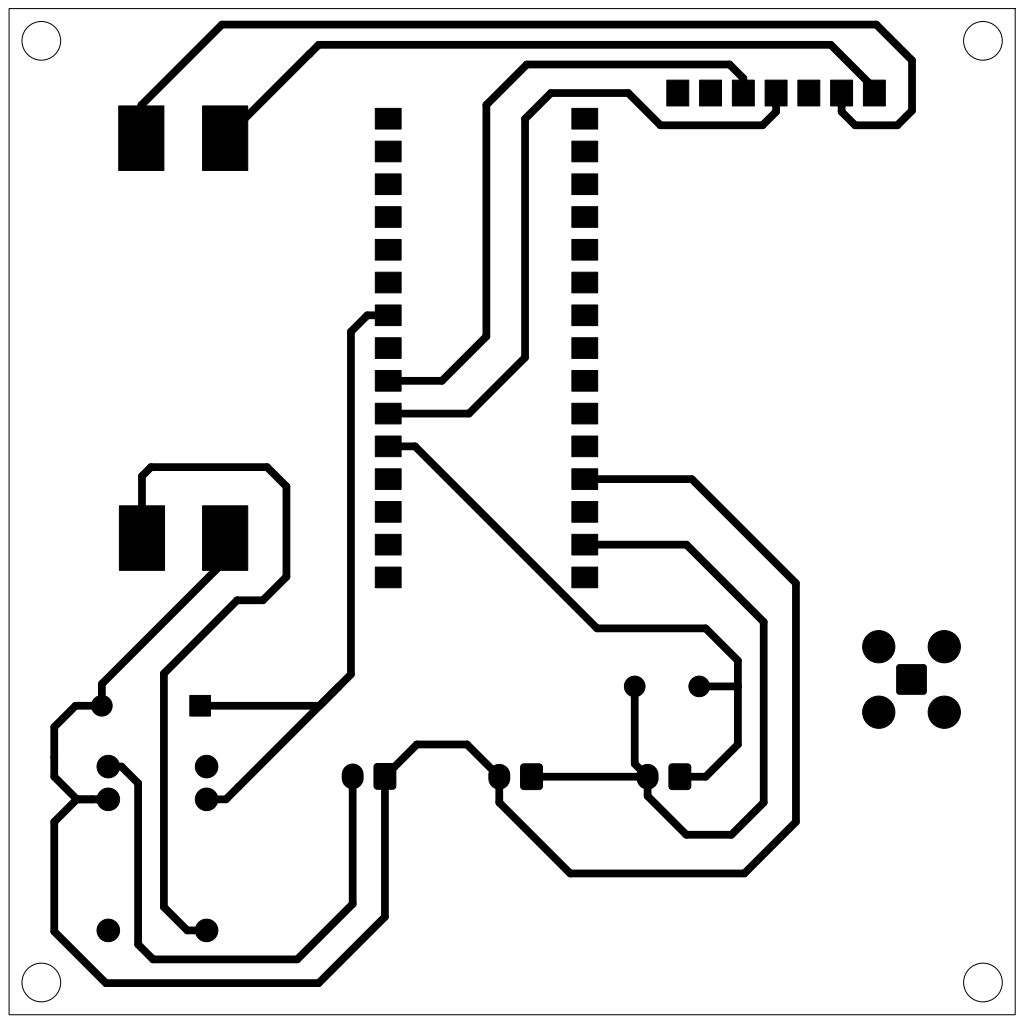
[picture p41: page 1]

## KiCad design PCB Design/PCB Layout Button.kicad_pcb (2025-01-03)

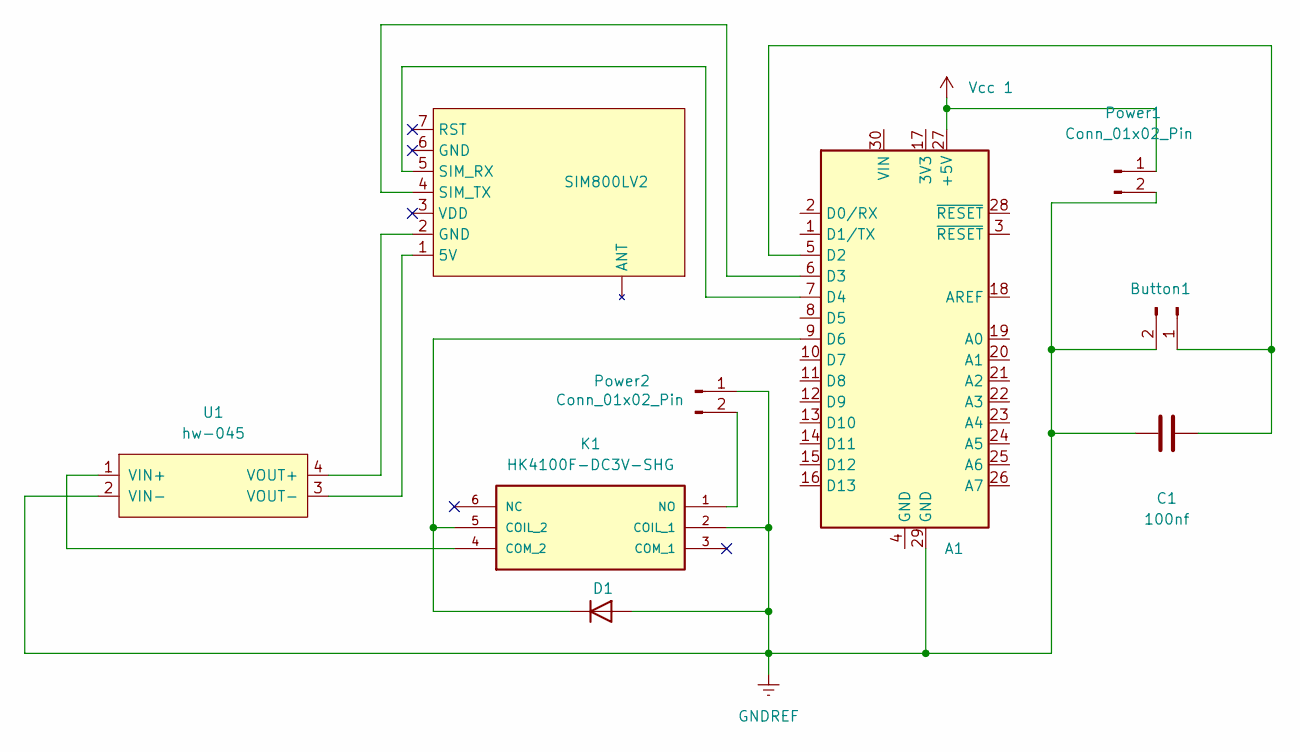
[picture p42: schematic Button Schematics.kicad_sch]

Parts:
A1: Arduino_Nano_v3.x; Arduino_Nano
Button1: Conn_01x02_Pin; JST_EH_B2B-EH-A_1x02_P2.50mm_Vertical
C1: 100nf; C_Disc_D5.1mm_W3.2mm_P5.00mm
D1: D; D_DO-35_SOD27_P7.62mm_Horizontal
K1: HK4100F-DC3V-SHG; HK4100FDC5VSHG; MANUFACTURER_PART_NUMBER HK4100F-DC5V-SHG
Power1, Power2: Conn_01x02_Pin; JST_EH_B2B-EH-A_1x02_P2.50mm_Vertical
SIM800LV2: SIM800
U1: hw-045; MT3608_module

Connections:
GNDREF: A1.29 (GND), Button1.2, C1.1, D1.2 (A), K1.2 (COIL_1), Power1.2, Power2.1, U1.2 (VIN-)
unnamed: A1.5 (D2), Button1.1, C1.2
unnamed: A1.6 (D3), SIM800LV2.4 (SIM_TX)
unnamed: A1.7 (D4), SIM800LV2.5 (SIM_RX)
unnamed: A1.9 (D6), D1.1 (K), K1.5 (COIL_2)
unnamed: K1.4 (COM_2), U1.1 (VIN+)
unnamed: K1.1 (NO), Power2.2
unnamed: SIM800LV2.1 (5V), U1.3 (VOUT-)
unnamed: SIM800LV2.2 (GND), U1.4 (VOUT+)
Vcc 1: A1.27 (+5V), Power1.1

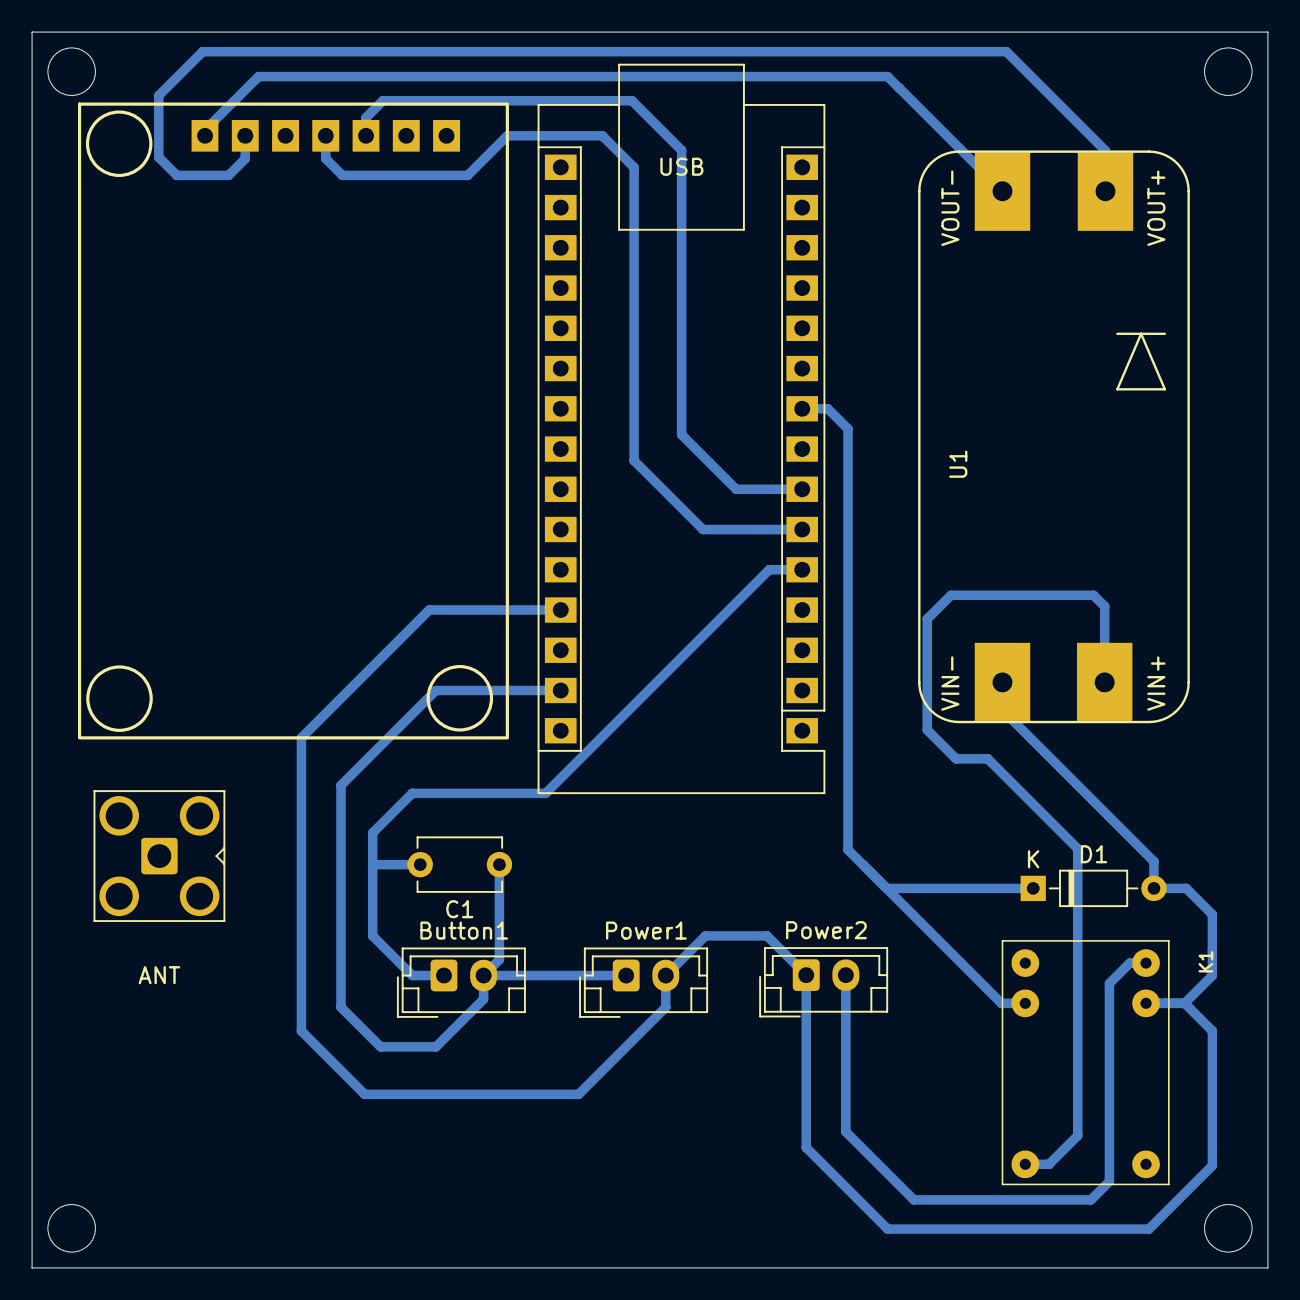
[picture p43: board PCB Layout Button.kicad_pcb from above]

Board: 2 copper layers, 78.0 x 78.0 mm, 10 parts (0 on the bottom side), 10 nets.

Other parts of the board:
ANT: SMA_Amphenol_901-143_Horizontal

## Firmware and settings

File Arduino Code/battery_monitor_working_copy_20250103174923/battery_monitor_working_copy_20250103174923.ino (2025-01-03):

  #include <stdlib.h>

  char buff[10];

  void setup() {
    Serial.begin(9600);
    pinMode(A0, INPUT);
  }

  void loop() {
    // Read normal Arduino value
    int in0 = analogRead(A0);
    float val0 = in0 * 5.0 / 1024.0;

    // Read correct supply voltage
    float supply = readVcc() / 1000.0;
    float val0Corrected = supply / 5 * val0;

    // Print values to Serial Monitor
  
    dtostrf(val0Corrected, 4, 3, buff);
    Serial.print("Corr: ");
    Serial.println(buff);
    
    delay(500);
  }

  long readVcc() {
    long result;
    // Read 1.1V reference against AVcc
  #if defined(__AVR_ATmega32U4__) || defined(__AVR_ATmega1280__) || defined(__AVR_ATmega2560__)
    ADMUX = _BV(REFS0) | _BV(MUX4) | _BV(MUX3) | _BV(MUX2) | _BV(MUX1);
  #elif defined (__AVR_ATtiny24__) || defined(__AVR_ATtiny44__) || defined(__AVR_ATtiny84__)
    ADMUX = _BV(MUX5) | _BV(MUX0);
  #elif defined (__AVR_ATtiny25__) || defined(__AVR_ATtiny45__) || defined(__AVR_ATtiny85__)
    ADMUX = _BV(MUX3) | _BV(MUX2);
  #else
    ADMUX = _BV(REFS0) | _BV(MUX3) | _BV(MUX2) | _BV(MUX1);
  #endif
    delay(2); // Wait for Vref to settle
    ADCSRA |= _BV(ADSC); // Convert
    while (bit_is_set(ADCSRA, ADSC));
    result = ADCL;
    result |= ADCH << 8;
    result = 1126400L / result; // Calculate Vcc (in mV); 1126400 = 1.1*1024*1000
    return result;
  }
